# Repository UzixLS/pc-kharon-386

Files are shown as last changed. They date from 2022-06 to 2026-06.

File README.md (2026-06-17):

## Kharon-386
10x10cm IBM PC compatible machine with 386 CPU, integrated VGA and sound.

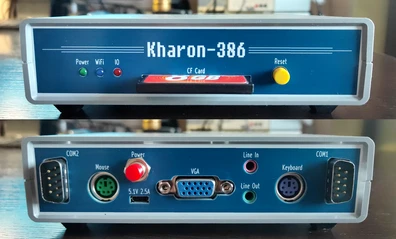
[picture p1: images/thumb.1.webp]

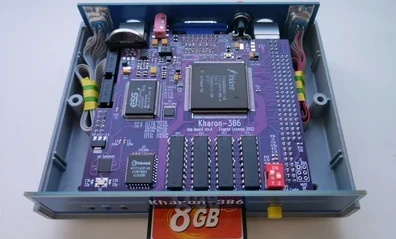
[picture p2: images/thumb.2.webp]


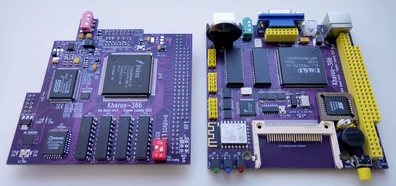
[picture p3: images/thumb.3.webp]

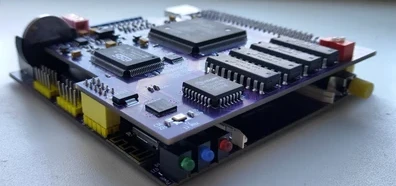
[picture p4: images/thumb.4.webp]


More random photos: [link](https://cloud.err200.net/index.php/s/73TR85tYZkMm8Ax?path=%2Fkharon-386)

### Tech specs
* M6117D System-On-Chip with integrated 386SX40 (almost compatible) CPU and M1217B chipset
* 4MB RAM
* TVGA9000i VGA video
* ES1868F SoundBlasterPro-compatible sound
* SAM2695 MIDI synthesizer
* ESP8266 WiFi module
* PS/2 keyboard and mouse inputs
* 2xCOM ports
* CF card slot
* Real-time clock (RTC) with backup battery
* Integrated PC-speaker
* 5.1V microUSB power
* Two 4-layer 10x10cm PCBs + front/back panel PCB
* G738 or G706 enclosure

### Navigation
[release/pcb_main.rev.A1.pdf](release/pcb_main.rev.A1.pdf) - motherboard schematic and bill of materials  
[release/pcb_top.rev.A1.pdf](release/pcb_top.rev.A1.pdf) - video&sound board schematic and bill of materials  
[release/bom_interactive_main.rev.A1.html](https://htmlpreview.github.io/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) - motherboard interactive BOM  
[release/bom_interactive_top.rev.A1.html](https://htmlpreview.github.io/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) - video&sound board interactive BOM  
[release/gerber_main.rev.A1.zip](release/gerber_main.rev.A1.zip) - motherboard fabrication files  
[release/gerber_top.rev.A1.zip](release/gerber_top.rev.A1.zip) - video&sound board fabrication files  
[release/gerber_covers.rev.A.zip](release/gerber_covers.rev.A.zip) - front and back panel fabrication files  
[roms/M6117 - award+ami.bin](roms/M6117%20-%20award+ami.bin) - main BIOS image  
[roms/tvga9000i - D3.51 + D4.01E.bin](roms/tvga9000i%20-%20D3.51%20%2B%20D4.01E.bin) - VGA BIOS image  
[software/msdos622_compactflash_2GB.7z](software/msdos622_compactflash_2GB.7z) - CF card image with preinstalled MS-DOS 6.22 and all necessary drivers

### WiFi module
There is two options how to use WiFi module:
1. Zimodem ([link](https://github.com/bozimmerman/Zimodem)) - provides ability to connect to BBS via any terminal without using additional software. WiFi module is connected to COM4, so you can use any terminal to communicate with it using AT commands.
2. esp_slip_router ([link](https://github.com/martin-ger/esp_slip_router)) - provides ability to connect your machine to IP network just like as Ethernet. You need ETHERSLIP or similar packet driver for DOS.

To upload firmware you need USB-UART adapter with 3.3V signal levels. Connect GND, RX and TX lines to esp header located on main PCB at left, install BOOT/GND jumper and follow any ESP8266 firmware update guide that is available on the internet.

### Sound mixer
MIDI synthesizer is connected to the AUXB sound input of ES1868F. Usually this input named as "CD input" in mixer software.  
PC speaker is connected to the AUXA input.  
To obtain a minimum noise level, it is recommended to disable line input in the mixer.

### Changelog & current status
Main PCB:
* Rev.A - first release. Please note the [errata](pcb_main/rev.A/ERRATA.txt);
* Rev.A1 - fixed all rev.A issues; added switch for BIOS variant select; added optional -5V source. Please note the [errata](pcb_main/rev.A1/ERRATA.txt).

Top PCB:
* Rev.A - first release. Please note the [errata](pcb_top/rev.A/ERRATA.txt);
* Rev.A1 - fixed all rev.A issues; added switch for VGA BIOS variant select; removed VGA-disable switch; added EEPROM for ES1868.

Covers PCB:
* Rev.A - first release.

### Related projects
I want to express my appreciation to the authors of the following projects, which served as inspiration and as reference for my development:

[http://www.alexandrugroza.ro/microelectronics/system-design/isa-80386dx-sbmc/index.html](http://www.alexandrugroza.ro/microelectronics/system-design/isa-80386dx-sbmc/index.html) - 80386DX ISA single board microcomputer by Alexandru Groza  
[https://bitbucket.org/Haper/poisk-2-mainboard/src/master/](https://bitbucket.org/Haper/poisk-2-mainboard/src/master/) - XT compatible 8086-based machine, reverse engineered by Andrew Khapoknysh ([details](https://habr.com/ru/articles/407265/))  
[http://www.malinov.com/Home/sergeys-projects/xi-8088](http://www.malinov.com/Home/sergeys-projects/xi-8088) - IBM PC/XT compatible processor board in ISA board form factor by by Sergey Kiselev  
[https://github.com/skiselev/micro_8088](https://github.com/skiselev/micro_8088) - IBM XT compatible processor board based on Faraday FE2010 chipset by Sergey Kiselev  
[https://github.com/monotech/NuXT](https://github.com/monotech/NuXT) -  MicroATX Turbo XT Motherboard, with VGA, floppy, CF, serial by Monotech  
[http://www.malinov.com/Home/sergeys-projects/isa-supervga](http://www.malinov.com/Home/sergeys-projects/isa-supervga) - ISA Super VGA card based on the Trident TVGA9000i Super VGA controller IC by Sergey Kiselev  
[https://github.com/monotech/PC104-SVGA](https://github.com/monotech/PC104-SVGA) - 8088-compatible 8-bit ISA PC/104 SVGA card by Monotech
[https://github.com/hkzlab/ES1868_ISA8](https://github.com/hkzlab/ES1868_ISA8) - ISA 8bit sound card based on the ES1868F sound chip by hkzlab

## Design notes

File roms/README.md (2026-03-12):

## ROM files

* **M6117 - award+ami.bin** — for the main PCB (U14) - system BIOS. Two alternative variants are included and can be selected using SW3. The AMI BIOS is recommended.
* **tvga9000i - D3.51 + D4.01E.bin** — for the top PCB (U7); video BIOS. Two alternative variants are included and can be selected using SW1.1.
* **AT93C66-dump.bin** — for the top PCB (U10); sound card PnP options. This ROM is optional, use it only if you experience problems with IRQ/DMA resource assignment.

All ROMs must be flashed before being soldered onto the PCB; in-circuit programming is not possible.

You can use any suitable ROM programmer (for example, TL866II). For detailed instructions, refer to the manufacturer’s manual.

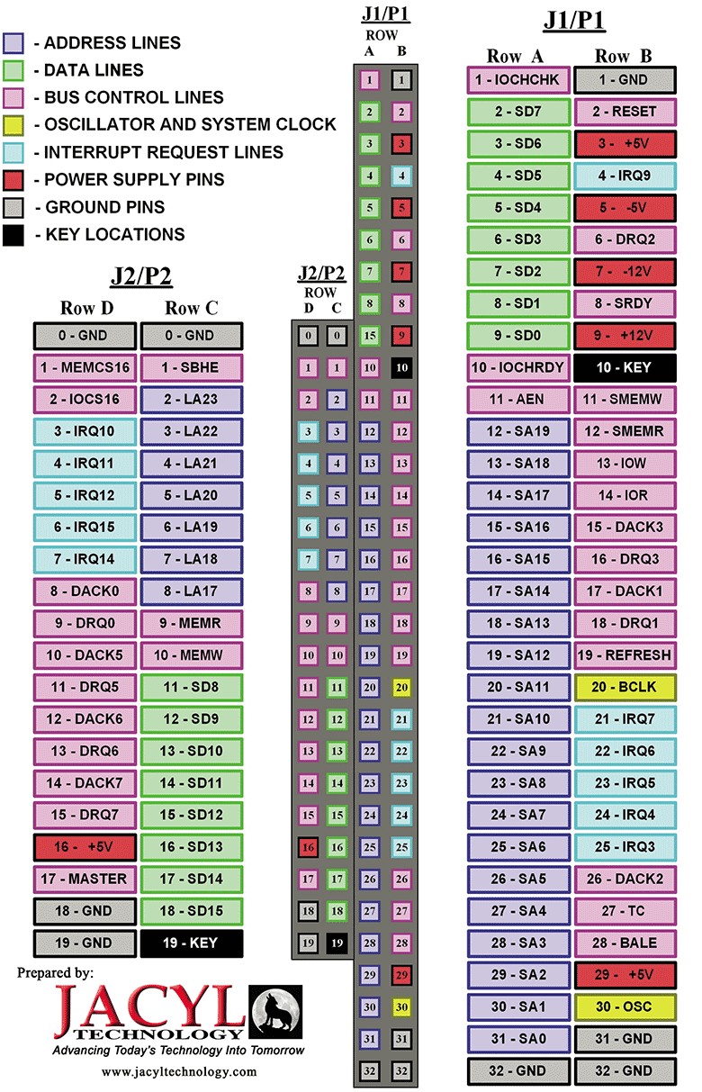
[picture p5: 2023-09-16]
datasheets/pc104.jpeg

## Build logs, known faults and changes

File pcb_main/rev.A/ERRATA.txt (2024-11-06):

1. Incorrect reset circuit
2. Unstable -12V under load. 1k resistor should be added between +12V and GND
3. BIOS PLCC socked interferes with CF card slot
4. U15 should be TXS0104PW
5. Incorrent IRQ routing for COM3 and COM4
6. U17 should not be installed
7. Incorrect CTS/RTS connection on ESP8266
8. C3 should not be installed

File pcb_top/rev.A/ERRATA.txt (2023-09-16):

1. ES1868F sounds too quiet
   - R10, R12 should be 0 Ohm
   - R14, R15 should not be installed
   - C20, C25 should be 1 uF
   - R11, R13 should be 10 KOhm
2. ES1868F footprint is a bit smaller than required, so soldering it may be tricky

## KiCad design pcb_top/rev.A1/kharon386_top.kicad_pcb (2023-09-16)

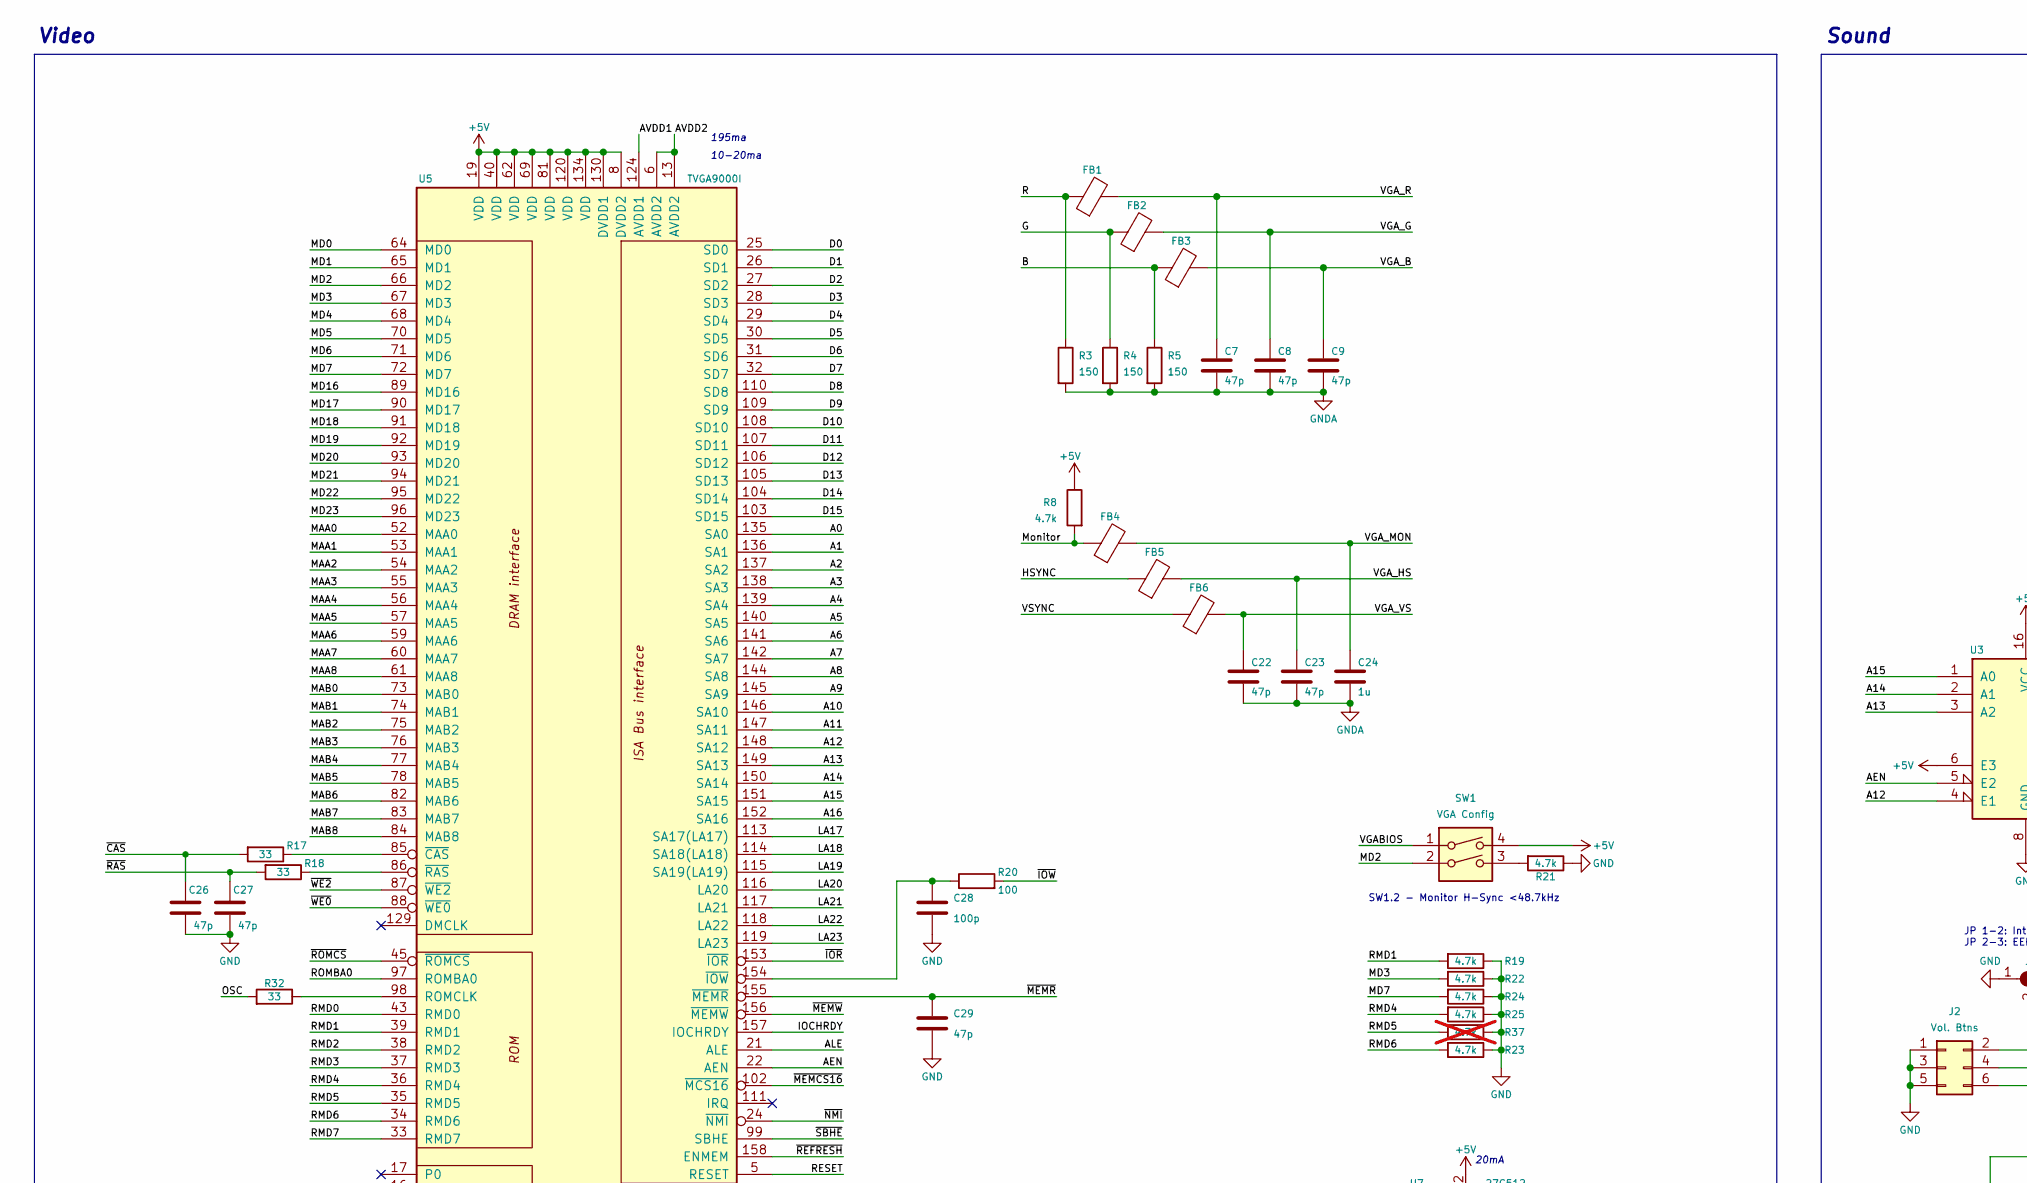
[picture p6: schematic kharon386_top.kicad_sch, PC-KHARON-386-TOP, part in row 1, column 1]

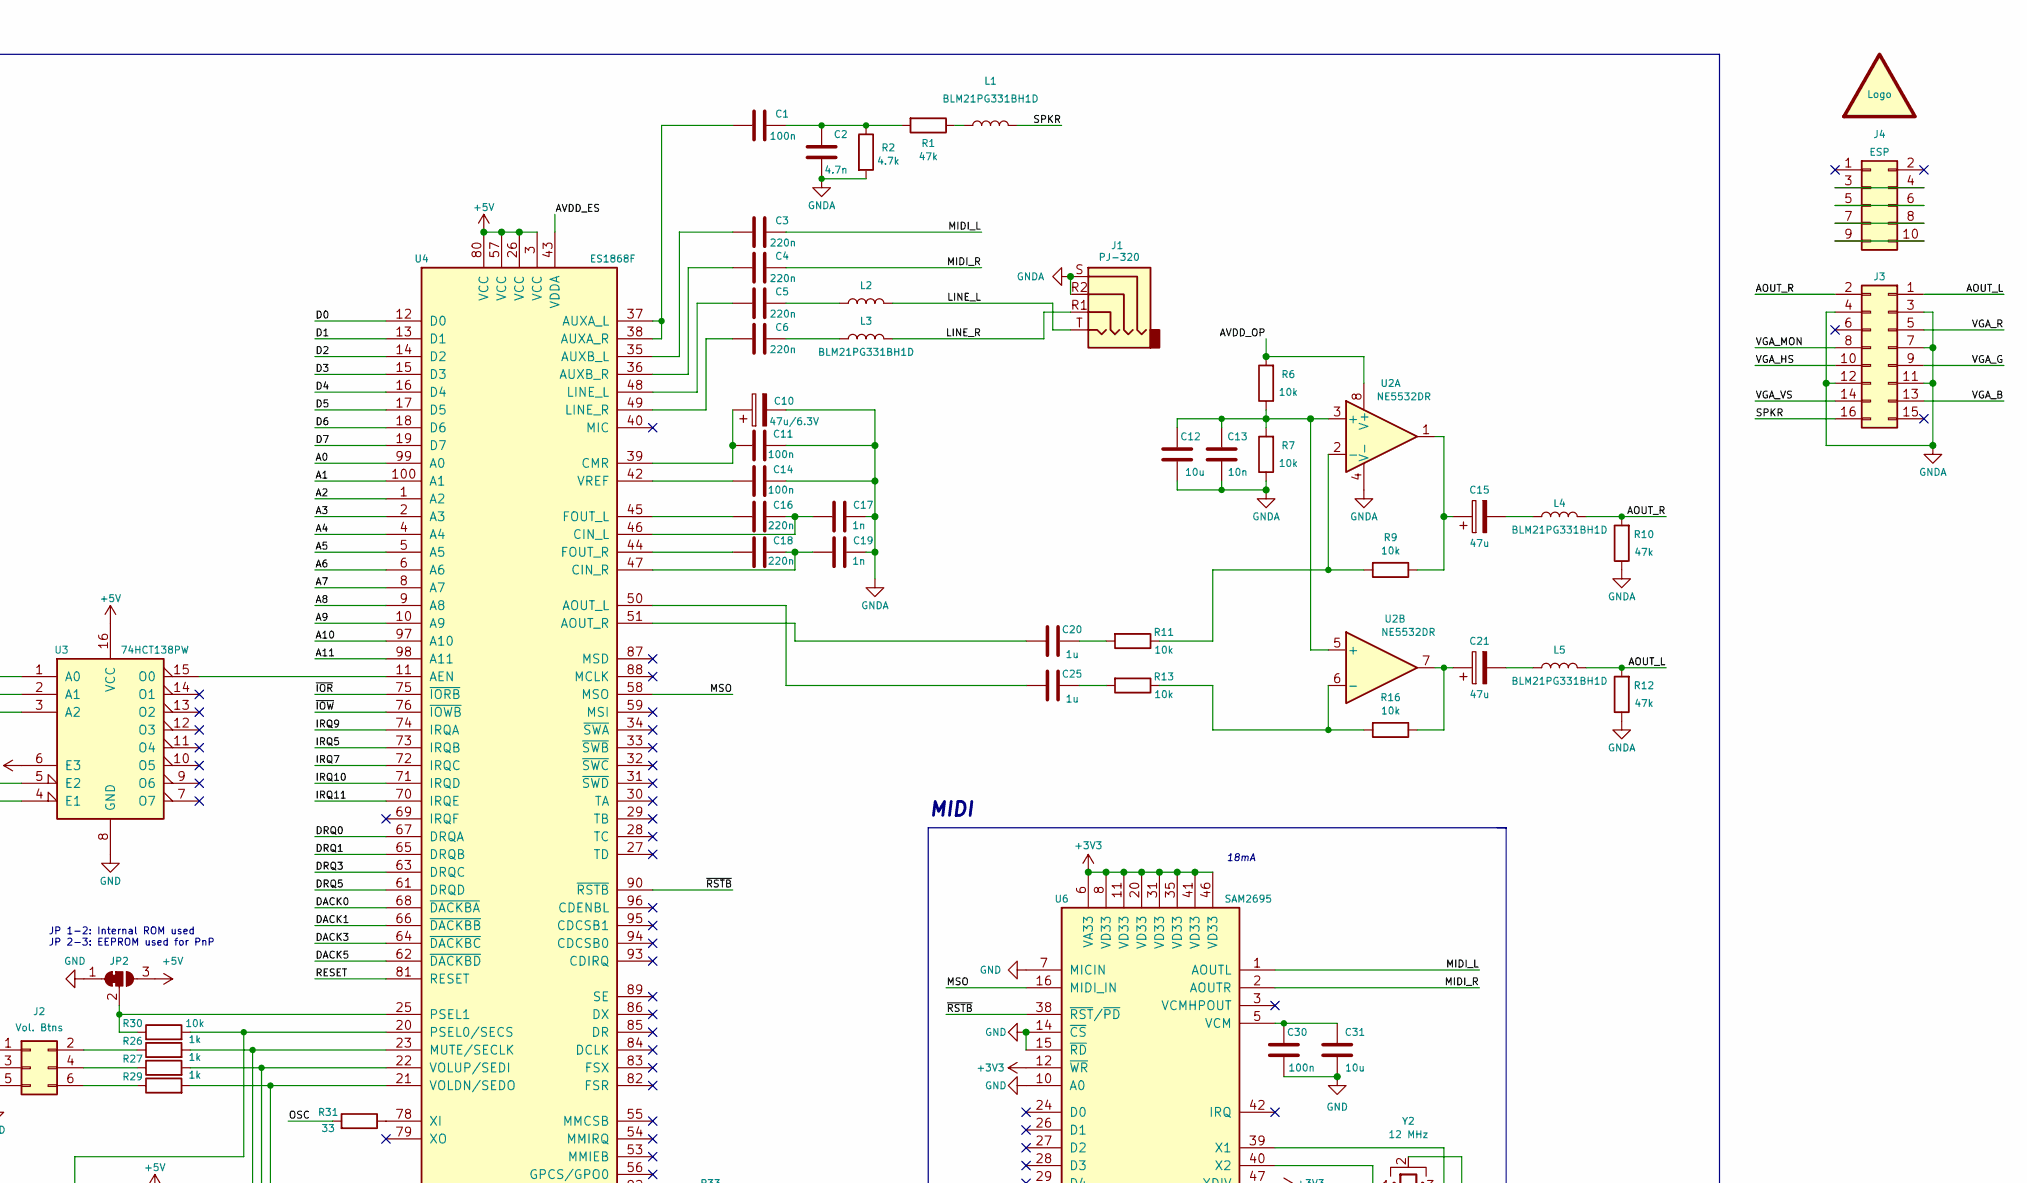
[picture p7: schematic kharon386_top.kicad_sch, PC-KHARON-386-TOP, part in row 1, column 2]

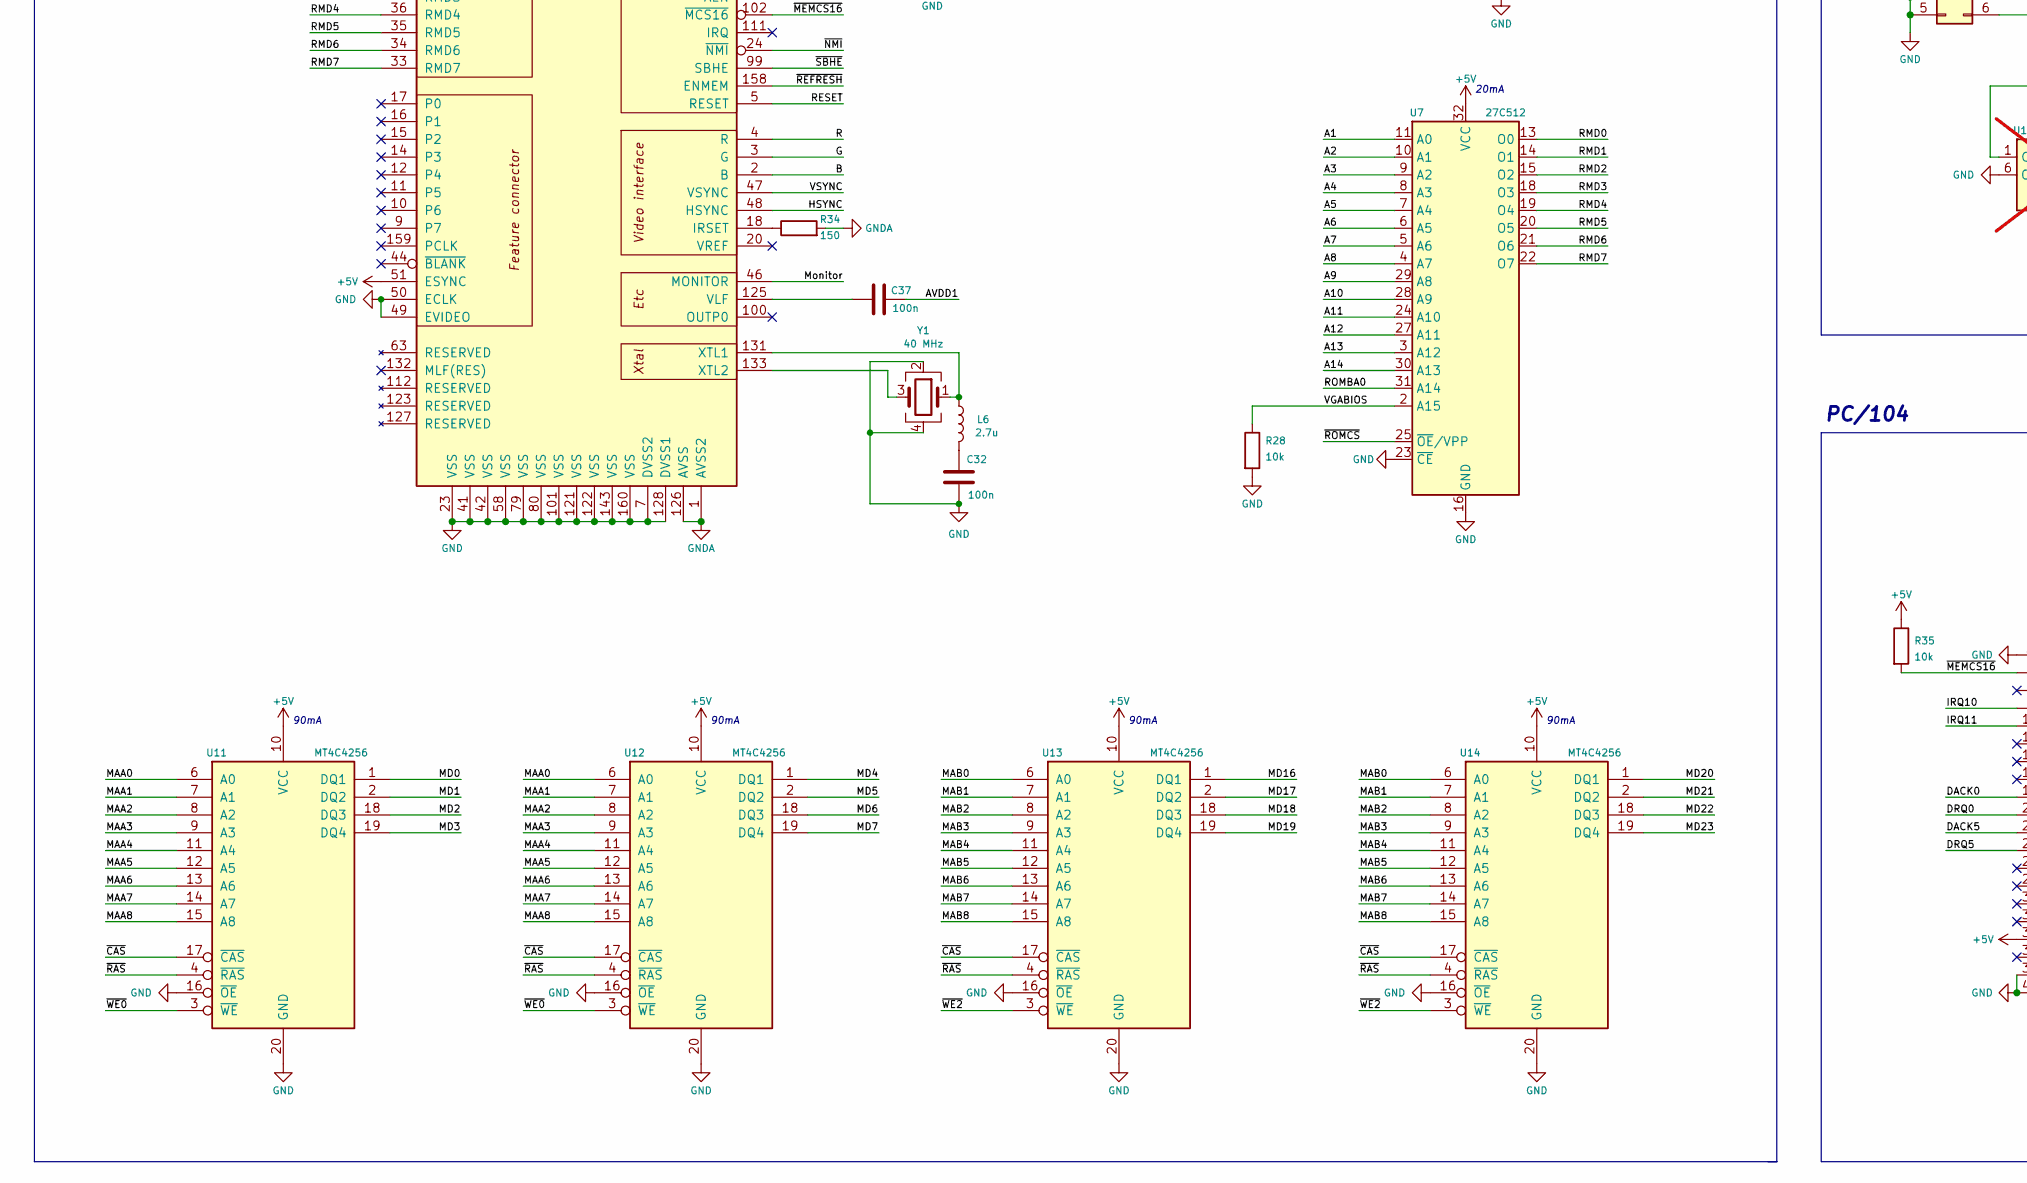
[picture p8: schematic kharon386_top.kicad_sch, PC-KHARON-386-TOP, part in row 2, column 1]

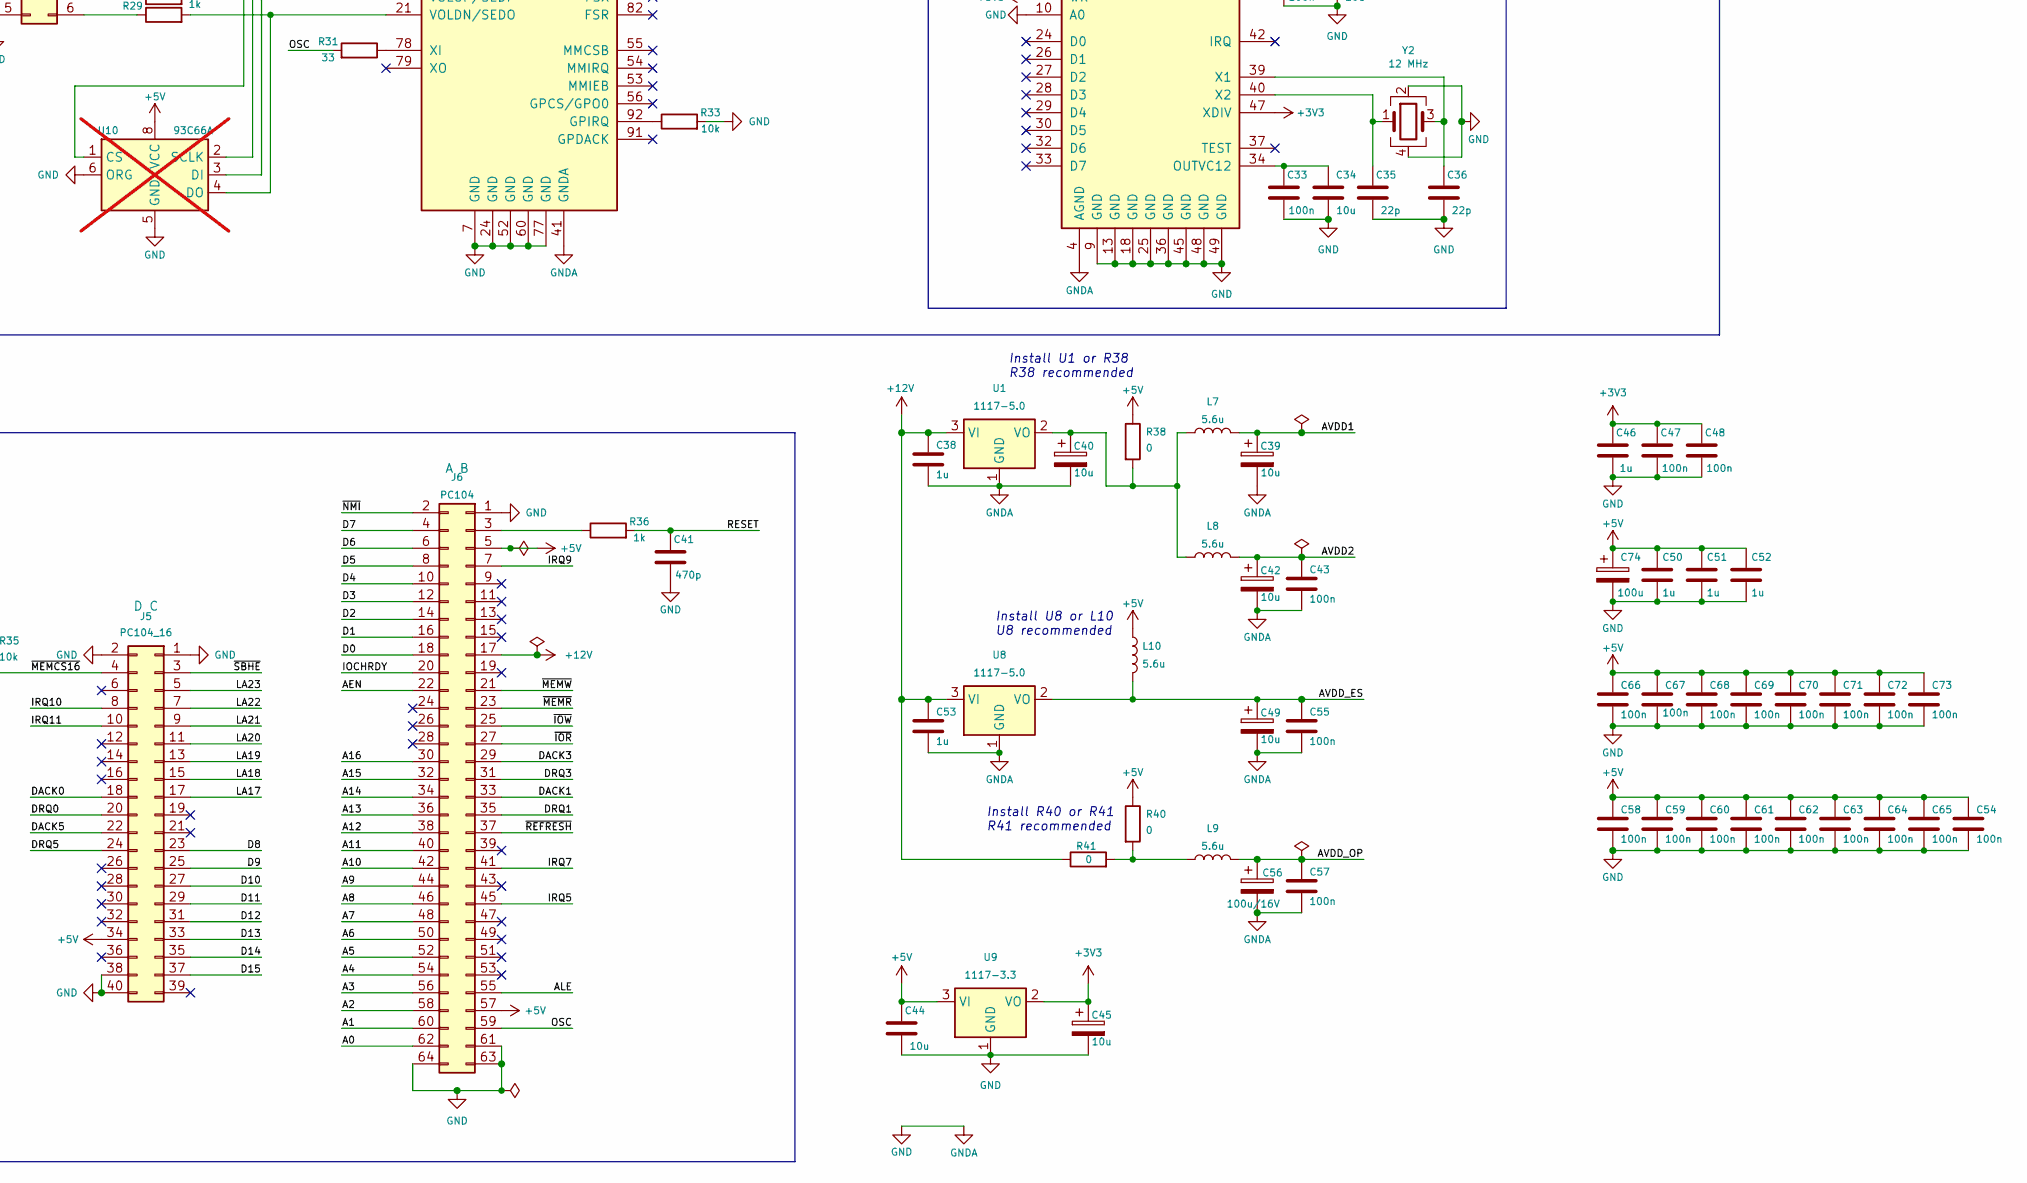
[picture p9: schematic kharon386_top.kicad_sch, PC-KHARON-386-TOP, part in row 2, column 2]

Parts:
C1, C11, C14, C30, C32, C33, C37, C43, C47, C48, C54, C55, C57, C58, C59, C60, C61, C62, C63, C64, C65, C66, C67, C68, C69, C70, C71, C72, C73: 100n; C_0603_1608Metric_Pad1.08x0.95mm_HandSolder
C2: 4.7n; C_0603_1608Metric_Pad1.08x0.95mm_HandSolder
C3, C4, C5, C6, C16, C18: 220n; C_0603_1608Metric_Pad1.08x0.95mm_HandSolder
C7, C8, C9, C22, C23, C26, C27, C29: 47p; C_0603_1608Metric_Pad1.08x0.95mm_HandSolder
C10: 47u/6.3V; CP_EIA-3528-21_Kemet-B_Pad1.50x2.35mm_HandSolder
C12, C31, C34, C44: 10u; C_0805_2012Metric_Pad1.18x1.45mm_HandSolder
C13: 10n; C_0603_1608Metric_Pad1.08x0.95mm_HandSolder
C15, C21: 47u; CP_EIA-3528-21_Kemet-B_Pad1.50x2.35mm_HandSolder
C17, C19: 1n; C_0603_1608Metric_Pad1.08x0.95mm_HandSolder
C20, C24, C25, C38, C46, C50, C51, C52, C53: 1u; C_0603_1608Metric_Pad1.08x0.95mm_HandSolder
C28: 100p; C_0603_1608Metric_Pad1.08x0.95mm_HandSolder
C35, C36: 22p; C_0603_1608Metric_Pad1.08x0.95mm_HandSolder
C39, C40, C42, C45, C49: 10u; CP_EIA-3216-18_Kemet-A_Pad1.58x1.35mm_HandSolder
C41: 470p; C_0603_1608Metric_Pad1.08x0.95mm_HandSolder
C56: 100u/16V; CP_EIA-6032-28_Kemet-C_Pad2.25x2.35mm_HandSolder
C74: 100u; CP_EIA-7343-31_Kemet-D_Pad2.25x2.55mm_HandSolder
FB1, FB2, FB3, FB4, FB5, FB6: Ferrite_Bead; L_0805_2012Metric_Pad1.15x1.40mm_HandSolder
J1: PJ-320; PJ-320A_D
J2: Vol. Btns; PinHeader_2x03_P2.54mm_Vertical
J3: Conn_02x07_Odd_Even; PinHeader_2x08_P2.54mm_Vertical
J4: ESP; PinSocket_2x05_P2.54mm_Vertical
J5: PC104_16; PinHeader_2x20_P2.54mm_Vertical
J6: PC104; PinHeader_2x32_P2.54mm_Vertical
JP2: SolderJumper_3_Bridged12; SolderJumper-3_P1.3mm_Bridged12_RoundedPad1.0x1.5mm_NumberL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
L1, L2, L3, L4, L5: BLM21PG331BH1D; L_0805_2012Metric_Pad1.15x1.40mm_HandSolder
L6: 2.7u; L_0805_2012Metric_Pad1.15x1.40mm_HandSolder
L7, L8, L9, L10: 5.6u; L_1210_3225Metric_Pad1.42x2.65mm_HandSolder
LOGO1: graphic; black-mage-12.5x8.6
R1, R10, R12: 47k; R_0603_1608Metric_Pad0.98x0.95mm_HandSolder
R2, R8, R19, R21, R22, R23, R24, R25: 4.7k; R_0603_1608Metric_Pad0.98x0.95mm_HandSolder
R3, R4, R5, R34: 150; R_0603_1608Metric_Pad0.98x0.95mm_HandSolder
R6, R7, R9, R11, R13, R16, R28, R30, R33, R35: 10k; R_0603_1608Metric_Pad0.98x0.95mm_HandSolder
R17, R18, R31, R32: 33; R_0603_1608Metric_Pad0.98x0.95mm_HandSolder
R20: 100; R_0603_1608Metric_Pad0.98x0.95mm_HandSolder
R26, R27, R29, R36: 1k; R_0603_1608Metric_Pad0.98x0.95mm_HandSolder
R37: 4.7k; R_0603_1608Metric_Pad0.98x0.95mm_HandSolder; not fitted
R38, R40, R41: 0; R_0805_2012Metric_Pad1.20x1.40mm_HandSolder
SW1: VGA Config; SW_DIP_SPSTx02_Slide_6.7x6.64mm_W7.62mm_P2.54mm_LowProfile
U1, U8: 1117-5.0; SOT-223-3_TabPin2
U2: NE5532DR; SOIC-8_3.9x4.9mm_P1.27mm
U3: 74HCT138PW; TSSOP-16_4.4x5mm_P0.65mm
U4: ES1868F; PQFP-100_14x20mm_P0.65mm_ESxxx
U5: TVGA9000I; PQFP-160_28x28mm_P0.65mm_LongPads
U6: SAM2695; QFN-48-1EP_6x6mm_P0.4mm_EP4.2x4.2mm
U7: 27C512; PLCC-32_11.4x14.0mm_P1.27mm-longpads
U9: 1117-3.3; SOT-223-3_TabPin2
U10: 93C66A; SOIC-8_3.9x4.9mm_P1.27mm; not fitted
U11, U12, U13, U14: MT4C4256; DIP-20_W7.62mm
Y1: 40 MHz; Crystal_SMD_SeikoEpson_TSX3225-4Pin_3.2x2.5mm_HandSoldering
Y2: 12 MHz; Crystal_SMD_SeikoEpson_TSX3225-4Pin_3.2x2.5mm_HandSoldering

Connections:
+3V3: C45.1, C46.2, C47.2, C48.2, U6.6 (VA33), U6.8 (VD33), U6.11 (VD33), U6.12 (~WR), U6.20 (VD33), U6.31 (VD33), U6.35 (VD33), U6.41 (VD33), U6.46 (VD33), U6.47 (XDIV), U9.2 (VO)
+5V: C44.2, C50.1, C51.1, C52.1, C54.1, C58.1, C59.1, C60.1, C61.1, C62.1, C63.1, C64.1, C65.1, C66.1, C67.1, C68.1, C69.1, C70.1, C71.1, C72.1, C73.1, C74.1, J5.34, J6.5, J6.57, JP2.3 (B), L10.1, R8.1, R35.1, R38.1, R40.1, SW1.4, U3.6 (E3), U3.16 (VCC), U4.3 (VCC), U4.26 (VCC), U4.57 (VCC), U4.80 (VCC), U5.8 (DVDD2), U5.19 (VDD), U5.40 (VDD), U5.51 (ESYNC), U5.62 (VDD), U5.69 (VDD), U5.81 (VDD), U5.120 (VDD), U5.130 (DVDD1), U5.134 (VDD), U7.32 (VCC), U9.3 (VI), U10.8 (VCC), U11.10 (VCC), U12.10 (VCC), U13.10 (VCC), U14.10 (VCC)
+12V: C38.1, C53.1, J6.17, R41.1, U1.3 (VI), U8.3 (VI)
/A0: J6.62, U4.99 (A0), U5.135 (SA0)
/A1: J6.60, U4.100 (A1), U5.136 (SA1), U7.11 (A0)
/A2: J6.58, U4.1 (A2), U5.137 (SA2), U7.10 (A1)
/A3: J6.56, U4.2 (A3), U5.138 (SA3), U7.9 (A2)
/A4: J6.54, U4.4 (A4), U5.139 (SA4), U7.8 (A3)
/A5: J6.52, U4.5 (A5), U5.140 (SA5), U7.7 (A4)
/A6: J6.50, U4.6 (A6), U5.141 (SA6), U7.6 (A5)
/A7: J6.48, U4.8 (A7), U5.142 (SA7), U7.5 (A6)
/A8: J6.46, U4.9 (A8), U5.144 (SA8), U7.4 (A7)
/A9: J6.44, U4.10 (A9), U5.145 (SA9), U7.29 (A8)
/A10: J6.42, U4.97 (A10), U5.146 (SA10), U7.28 (A9)
/A11: J6.40, U4.98 (A11), U5.147 (SA11), U7.24 (A10)
/A12: J6.38, U3.4 (E1), U5.148 (SA12), U7.27 (A11)
/A13: J6.36, U3.3 (A2), U5.149 (SA13), U7.3 (A12)
/A14: J6.34, U3.2 (A1), U5.150 (SA14), U7.30 (A13)
/A15: J6.32, U3.1 (A0), U5.151 (SA15)
/A16: J6.30, U5.152 (SA16)
/AEN: J6.22, U3.5 (E2), U5.22 (AEN)
/ALE: J6.55, U5.21 (ALE)
/AOUT_L: J3.1, L5.2, R12.2
/AOUT_R: J3.2, L4.2, R10.2
/AVDD1: C37.2, C39.1, L7.2, U5.124 (AVDD1)
/AVDD2: C42.1, C43.1, L8.2, U5.6 (AVDD2), U5.13 (AVDD2)
/AVDD_ES: C49.1, C55.1, L10.2, U4.43 (VDDA), U8.2 (VO)
/AVDD_OP: C56.1, C57.1, L9.2, R6.2, U2.8 (V+)
/B: FB3.1, R5.1, U5.2 (B)
/D0: J6.18, U4.12 (D0), U5.25 (SD0)
/D1: J6.16, U4.13 (D1), U5.26 (SD1)
/D2: J6.14, U4.14 (D2), U5.27 (SD2)
/D3: J6.12, U4.15 (D3), U5.28 (SD3)
/D4: J6.10, U4.16 (D4), U5.29 (SD4)
/D5: J6.8, U4.17 (D5), U5.30 (SD5)
/D6: J6.6, U4.18 (D6), U5.31 (SD6)
/D7: J6.4, U4.19 (D7), U5.32 (SD7)
/D8: J5.23, U5.110 (SD8)
/D9: J5.25, U5.109 (SD9)
/D10: J5.27, U5.108 (SD10)
/D11: J5.29, U5.107 (SD11)
/D12: J5.31, U5.106 (SD12)
/D13: J5.33, U5.105 (SD13)
/D14: J5.35, U5.104 (SD14)
/D15: J5.37, U5.103 (SD15)
/DACK0: J5.18, U4.68 (~DACKBA)
/DACK1: J6.33, U4.66 (~DACKBB)
/DACK3: J6.29, U4.64 (~DACKBC)
/DACK5: J5.22, U4.62 (~DACKBD)
/DRQ0: J5.20, U4.67 (DRQA)
/DRQ1: J6.35, U4.65 (DRQB)
/DRQ3: J6.31, U4.63 (DRQC)
/DRQ5: J5.24, U4.61 (DRQD)
/G: FB2.1, R4.1, U5.3 (G)
/HSYNC: FB5.1, U5.48 (HSYNC)
/IOCHRDY: J6.20, U5.157 (IOCHRDY)
/IRQ5: J6.45, U4.73 (IRQB)
/IRQ7: J6.41, U4.72 (IRQC)
/IRQ9: J6.7, U4.74 (IRQA)
/IRQ10: J5.8, U4.71 (IRQD)
/IRQ11: J5.10, U4.70 (IRQE)
/LA17: J5.17, U5.113 (SA17(LA17))
/LA18: J5.15, U5.114 (SA18(LA18))
/LA19: J5.13, U5.115 (SA19(LA19))
/LA20: J5.11, U5.116 (LA20)
/LA21: J5.9, U5.117 (LA21)
/LA22: J5.7, U5.118 (LA22)
/LA23: J5.5, U5.119 (LA23)
/LINE_L: J1.T, L2.2
/LINE_R: J1.R1, L3.2
/MAA0: U5.52 (MAA0), U11.6 (A0), U12.6 (A0)
/MAA1: U5.53 (MAA1), U11.7 (A1), U12.7 (A1)
/MAA2: U5.54 (MAA2), U11.8 (A2), U12.8 (A2)
/MAA3: U5.55 (MAA3), U11.9 (A3), U12.9 (A3)
/MAA4: U5.56 (MAA4), U11.11 (A4), U12.11 (A4)
/MAA5: U5.57 (MAA5), U11.12 (A5), U12.12 (A5)
/MAA6: U5.59 (MAA6), U11.13 (A6), U12.13 (A6)
/MAA7: U5.60 (MAA7), U11.14 (A7), U12.14 (A7)
/MAA8: U5.61 (MAA8), U11.15 (A8), U12.15 (A8)
/MAB0: U5.73 (MAB0), U13.6 (A0), U14.6 (A0)
/MAB1: U5.74 (MAB1), U13.7 (A1), U14.7 (A1)
/MAB2: U5.75 (MAB2), U13.8 (A2), U14.8 (A2)
/MAB3: U5.76 (MAB3), U13.9 (A3), U14.9 (A3)
/MAB4: U5.77 (MAB4), U13.11 (A4), U14.11 (A4)
/MAB5: U5.78 (MAB5), U13.12 (A5), U14.12 (A5)
/MAB6: U5.82 (MAB6), U13.13 (A6), U14.13 (A6)
/MAB7: U5.83 (MAB7), U13.14 (A7), U14.14 (A7)
/MAB8: U5.84 (MAB8), U13.15 (A8), U14.15 (A8)
/MD0: U5.64 (MD0), U11.1 (DQ1)
/MD1: U5.65 (MD1), U11.2 (DQ2)
/MD2: SW1.2, U5.66 (MD2), U11.18 (DQ3)
/MD3: R22.2, U5.67 (MD3), U11.19 (DQ4)
/MD4: U5.68 (MD4), U12.1 (DQ1)
/MD5: U5.70 (MD5), U12.2 (DQ2)
/MD6: U5.71 (MD6), U12.18 (DQ3)
/MD7: R24.2, U5.72 (MD7), U12.19 (DQ4)
/MD16: U5.89 (MD16), U13.1 (DQ1)
/MD17: U5.90 (MD17), U13.2 (DQ2)
/MD18: U5.91 (MD18), U13.18 (DQ3)
/MD19: U5.92 (MD19), U13.19 (DQ4)
/MD20: U5.93 (MD20), U14.1 (DQ1)
/MD21: U5.94 (MD21), U14.2 (DQ2)
/MD22: U5.95 (MD22), U14.18 (DQ3)
/MD23: U5.96 (MD23), U14.19 (DQ4)
/MIDI_L: C3.2, U6.1 (AOUTL)
/MIDI_R: C4.2, U6.2 (AOUTR)
/MSO: U4.58 (MSO), U6.16 (MIDI_IN)
/Monitor: FB4.1, R8.2, U5.46 (MONITOR)
/OSC: J6.59, R31.2, R32.2
/R: FB1.1, R3.1, U5.4 (R)
/RESET: C41.1, R36.2, U4.81 (RESET), U5.5 (RESET)
/RMD0: U5.43 (RMD0), U7.13 (O0)
/RMD1: R19.2, U5.39 (RMD1), U7.14 (O1)
/RMD2: U5.38 (RMD2), U7.15 (O2)
/RMD3: U5.37 (RMD3), U7.18 (O3)
/RMD4: R25.2, U5.36 (RMD4), U7.19 (O4)
/RMD5: R37.2, U5.35 (RMD5), U7.20 (O5)
/RMD6: R23.2, U5.34 (RMD6), U7.21 (O6)
/RMD7: U5.33 (RMD7), U7.22 (O7)
/ROMBA0: U5.97 (ROMBA0), U7.31 (A14)
/SPKR: J3.16, L1.2
/VGABIOS: R28.1, SW1.1, U7.2 (A15)
/VGA_B: C9.1, FB3.2, J3.13
/VGA_G: C8.1, FB2.2, J3.9
/VGA_HS: C23.1, FB5.2, J3.10
/VGA_MON: C24.1, FB4.2, J3.8
/VGA_R: C7.1, FB1.2, J3.5
/VGA_VS: C22.1, FB6.2, J3.14
/VSYNC: FB6.1, U5.47 (VSYNC)
/~CAS: C26.2, R17.2, U11.17 (~CAS), U12.17 (~CAS), U13.17 (~CAS), U14.17 (~CAS)
/~IOR: J6.27, U4.75 (~IORB), U5.153 (~IOR)
/~IOW: J6.25, R20.2, U4.76 (~IOWB)
/~MEMCS16: J5.4, R35.2, U5.102 (~MCS16)
/~MEMR: C29.1, J6.23, U5.155 (~MEMR)
/~MEMW: J6.21, U5.156 (~MEMW)
/~NMI: J6.2, U5.24 (~NMI)
/~RAS: C27.2, R18.2, U11.4 (~RAS), U12.4 (~RAS), U13.4 (~RAS), U14.4 (~RAS)
/~REFRESH: J6.37, U5.158 (ENMEM)
/~ROMCS: U5.45 (~ROMCS), U7.25 (~OE/VPP)
/~RSTB: U4.90 (~RSTB), U6.38 (~RST/~PD)
/~SBHE: J5.3, U5.99 (SBHE)
/~WE0: U5.88 (~WE0), U11.3 (~WE), U12.3 (~WE)
/~WE2: U5.87 (~WE2), U13.3 (~WE), U14.3 (~WE)
GND: C2.1, C7.2, C8.2, C9.2, C10.2, C11.2, C12.1, C13.1, C14.2, C17.2, C19.2, C22.2, C23.2, C24.2, C26.1, C27.1, C28.2, C29.2, C30.1, C31.1, C32.1, C33.1, C34.1, C35.1, C36.1, C38.2, C39.2, C40.2, C41.2, C42.2, C43.2, C44.1, C45.2, C46.1, C47.1, C48.1, C49.2, C50.2, C51.2, C52.2, C53.2, C54.2, C55.2, C56.2, C57.2, C58.2, C59.2, C60.2, C61.2, C62.2, C63.2, C64.2, C65.2, C66.2, C67.2, C68.2, C69.2, C70.2, C71.2, C72.2, C73.2, C74.2, J1.R2, J1.S, J2.1, J2.3, J2.5, J3.3, J3.4, J3.7, J3.11, J3.12, J5.1, J5.2, J5.38, J5.40, J6.1, J6.61, J6.63, J6.64, JP2.1 (A), R2.2, R3.2, R4.2, R5.2, R7.1, R10.1, R12.1, R19.1, R21.1, R22.1, R23.1, R24.1, R25.1, R28.2, R33.2, R34.2, R37.1, U1.1 (GND), U2.4 (V-), U3.8 (GND), U4.7 (GND), U4.24 (GND), U4.41 (GNDA), U4.52 (GND), U4.60 (GND), U4.77 (GND), U5.1 (AVSS2), U5.7 (DVSS2), U5.23 (VSS), U5.41 (VSS), U5.42 (VSS), U5.49 (EVIDEO), U5.50 (ECLK), U5.58 (VSS), U5.79 (VSS), U5.80 (VSS), U5.101 (VSS), U5.121 (VSS), U5.122 (VSS), U5.126 (AVSS), U5.128 (DVSS1), U5.143 (VSS), U5.160 (VSS), U6.4 (AGND), U6.7 (MICIN), U6.9 (GND), U6.10 (A0), U6.13 (GND), U6.14 (~CS), U6.15 (~RD), U6.18 (GND), U6.25 (GND), U6.36 (GND), U6.45 (GND), U6.48 (GND), U6.49 (GND), U7.16 (GND), U7.23 (~CE), U8.1 (GND), U9.1 (GND), U10.5 (GND), U10.6 (ORG), U11.16 (~OE), U11.20 (GND), U12.16 (~OE), U12.20 (GND), U13.16 (~OE), U13.20 (GND), U14.16 (~OE), U14.20 (GND), Y1.2, Y1.4, Y2.2, Y2.4
unnamed: C1.2, C2.2, R1.2, R2.1
unnamed: C5.2, L2.1
unnamed: C6.2, L3.1
unnamed: C15.1, R9.1, U2.1
unnamed: C15.2, L4.1
unnamed: C20.2, R11.2
unnamed: C21.1, R16.1, U2.7
unnamed: C21.2, L5.1
unnamed: C25.2, R13.2
unnamed: C32.2, L6.1
unnamed: J2.2, R26.1
unnamed: J2.4, R27.1
unnamed: J2.6, R29.1
unnamed: J4.3, J4.4
unnamed: J4.5, J4.6
unnamed: J4.7, J4.8
unnamed: J4.9, J4.10
unnamed: J6.3, R36.1
unnamed: JP2.2 (C), R30.1, U4.25 (PSEL1)
unnamed: L1.1, R1.1
unnamed: L9.1, R40.2, R41.2
unnamed: R21.2, SW1.3
unnamed: C40.1, L7.1, L8.1, R38.2, U1.2 (VO)
unnamed: C12.2, C13.2, R6.1, R7.2, U2.3 (+), U2.5 (+)
unnamed: R9.2, R11.1, U2.2 (-)
unnamed: R13.1, R16.2, U2.6 (-)
unnamed: U3.15 (O0), U4.11 (AEN)
unnamed: C25.1, U4.50 (AOUT_L)
unnamed: C20.1, U4.51 (AOUT_R)
unnamed: C1.1, U4.37 (AUXA_L), U4.38 (AUXA_R)
unnamed: C3.1, U4.35 (AUXB_L)
unnamed: C4.1, U4.36 (AUXB_R)
unnamed: C16.2, C17.1, U4.46 (CIN_L)
unnamed: C18.2, C19.1, U4.47 (CIN_R)
unnamed: C10.1, C11.1, U4.39 (CMR)
unnamed: C16.1, U4.45 (FOUT_L)
unnamed: C18.1, U4.44 (FOUT_R)
unnamed: R33.1, U4.92 (GPIRQ)
unnamed: C5.1, U4.48 (LINE_L)
unnamed: C6.1, U4.49 (LINE_R)
unnamed: C14.1, U4.42 (VREF)
unnamed: R31.1, U4.78 (XI)
unnamed: R34.1, U5.18 (IRSET)
unnamed: R32.1, U5.98 (ROMCLK)
unnamed: C37.1, U5.125 (VLF)
unnamed: L6.2, U5.131 (XTL1), Y1.1
unnamed: U5.133 (XTL2), Y1.3
unnamed: R17.1, U5.85 (~CAS)
unnamed: C28.1, R20.1, U5.154 (~IOW)
unnamed: R18.1, U5.86 (~RAS)
unnamed: C33.2, C34.2, U6.34 (OUTVC12)
unnamed: C30.2, C31.2, U6.5 (VCM)
unnamed: C36.2, U6.39 (X1), Y2.3
unnamed: C35.2, U6.40 (X2), Y2.1
unnamed: R30.2, U4.20 (PSEL0/SECS), U10.1 (CS)
unnamed: R27.2, U4.22 (VOLUP/SEDI), U10.3 (DI)
unnamed: R29.2, U4.21 (VOLDN/SEDO), U10.4 (DO)
unnamed: R26.2, U4.23 (MUTE/SECLK), U10.2 (SCLK)

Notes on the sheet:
10-20ma
JP 1-2: Internal ROM used JP 2-3: EEPROM used for PnP
SW1.2 - Monitor H-Sync <48.7kHz
90mA
18mA
195ma
Install U1 or R38 R38 recommended
Sound
Video
Install U8 or L10 U8 recommended
MIDI
20mA
Install R40 or R41 R41 recommended
PC/104

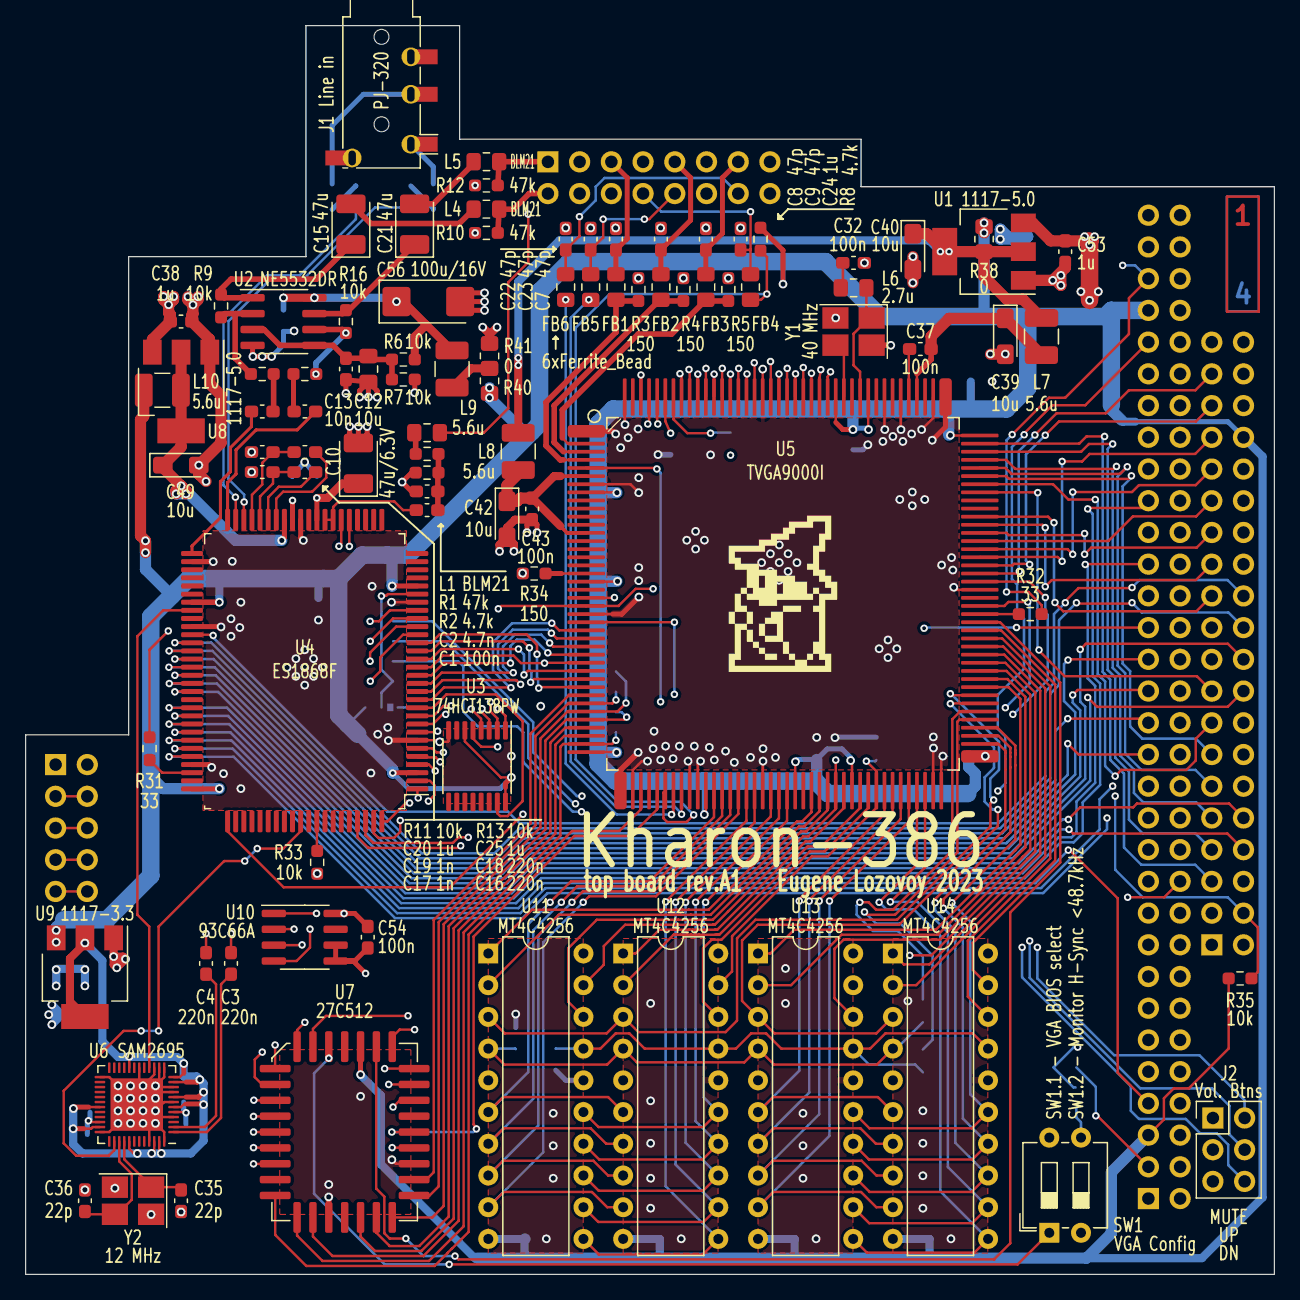
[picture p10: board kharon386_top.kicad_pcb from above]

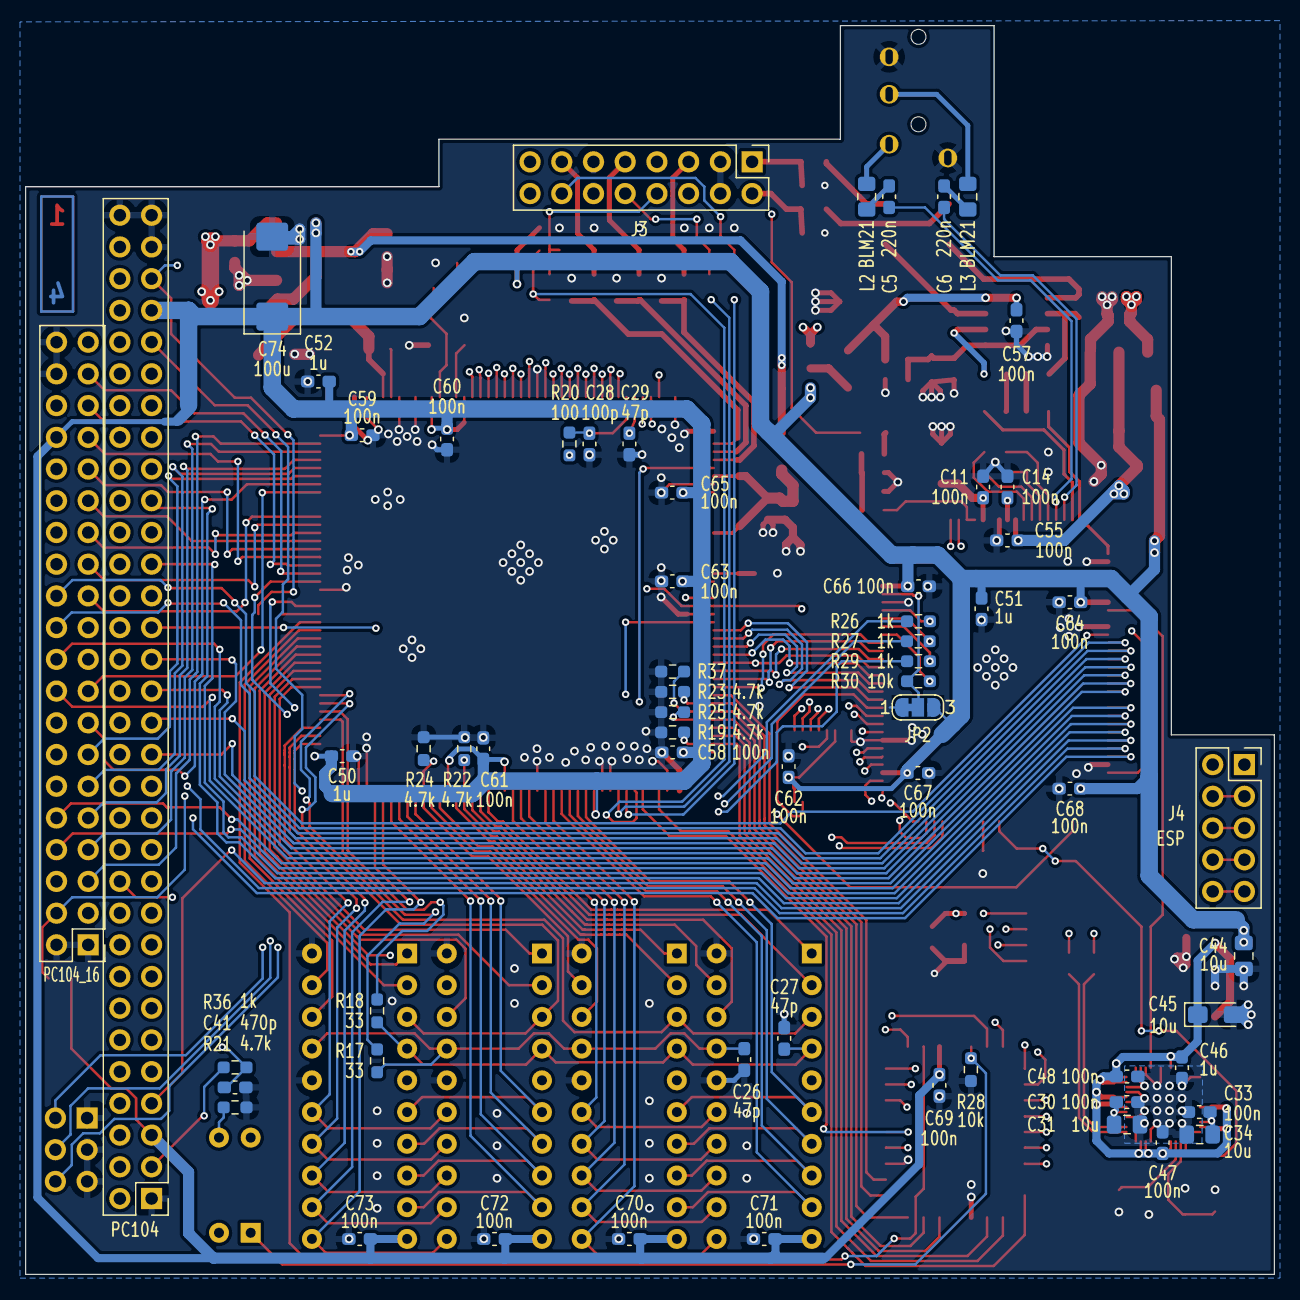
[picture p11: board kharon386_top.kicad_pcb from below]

Board: 4 copper layers, 100.0 x 100.0 mm, 153 parts (63 on the bottom side), 202 nets.

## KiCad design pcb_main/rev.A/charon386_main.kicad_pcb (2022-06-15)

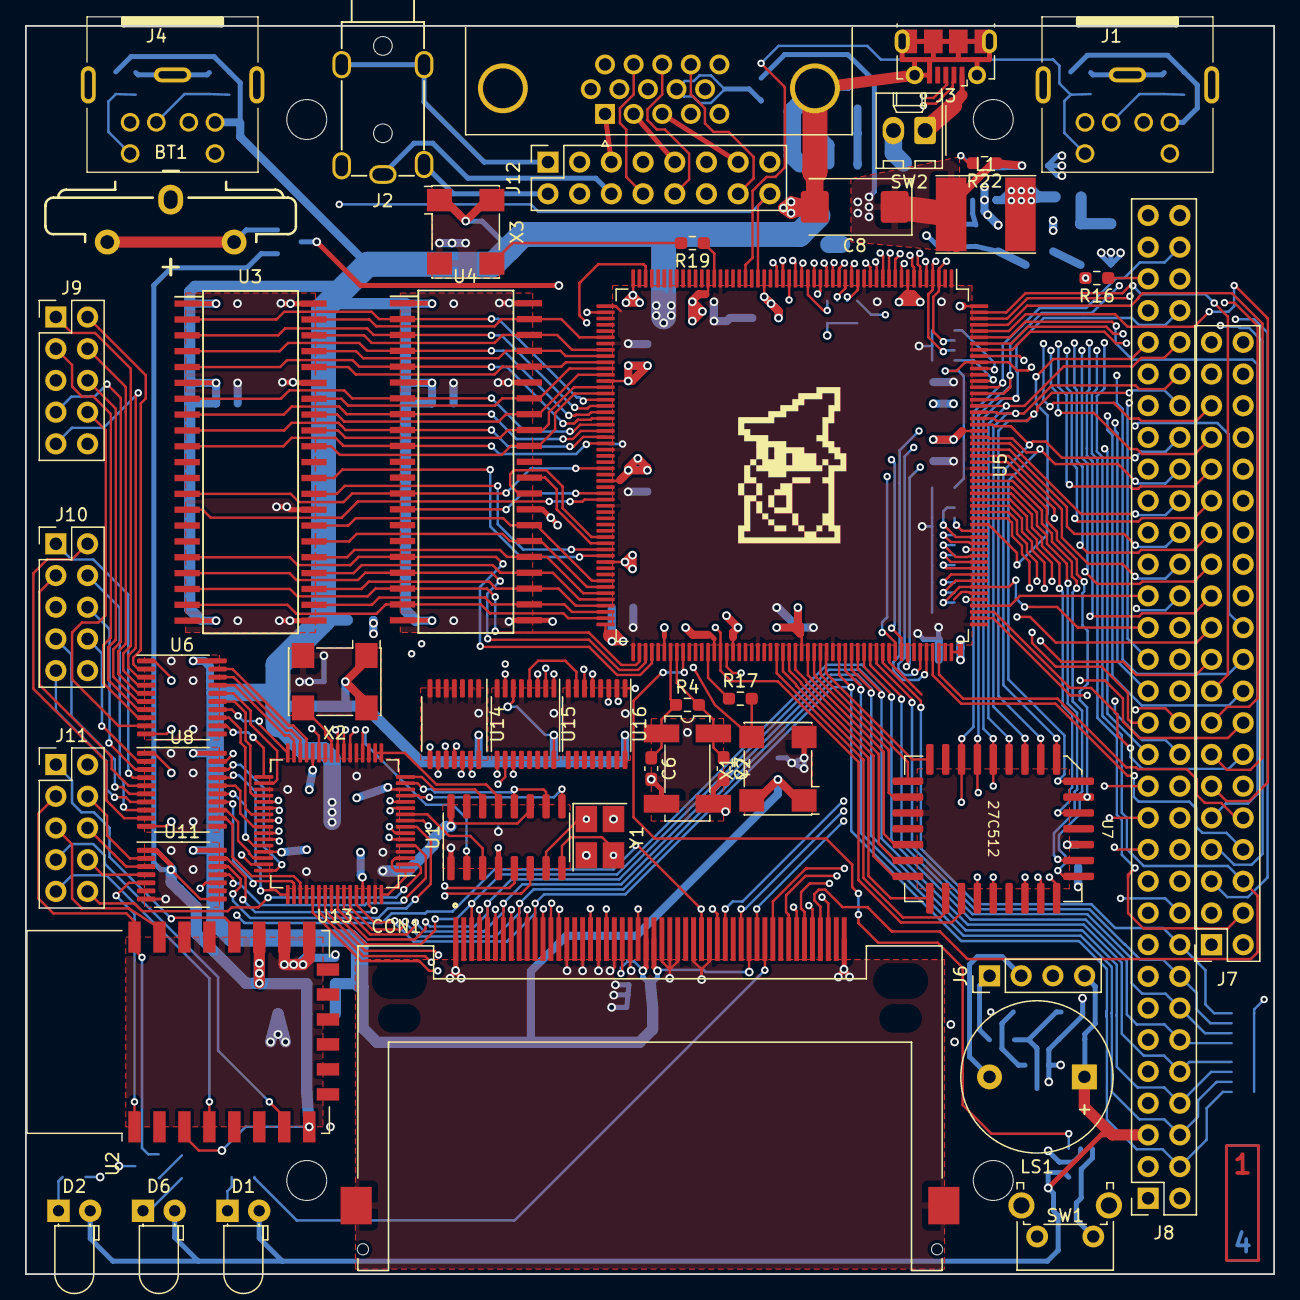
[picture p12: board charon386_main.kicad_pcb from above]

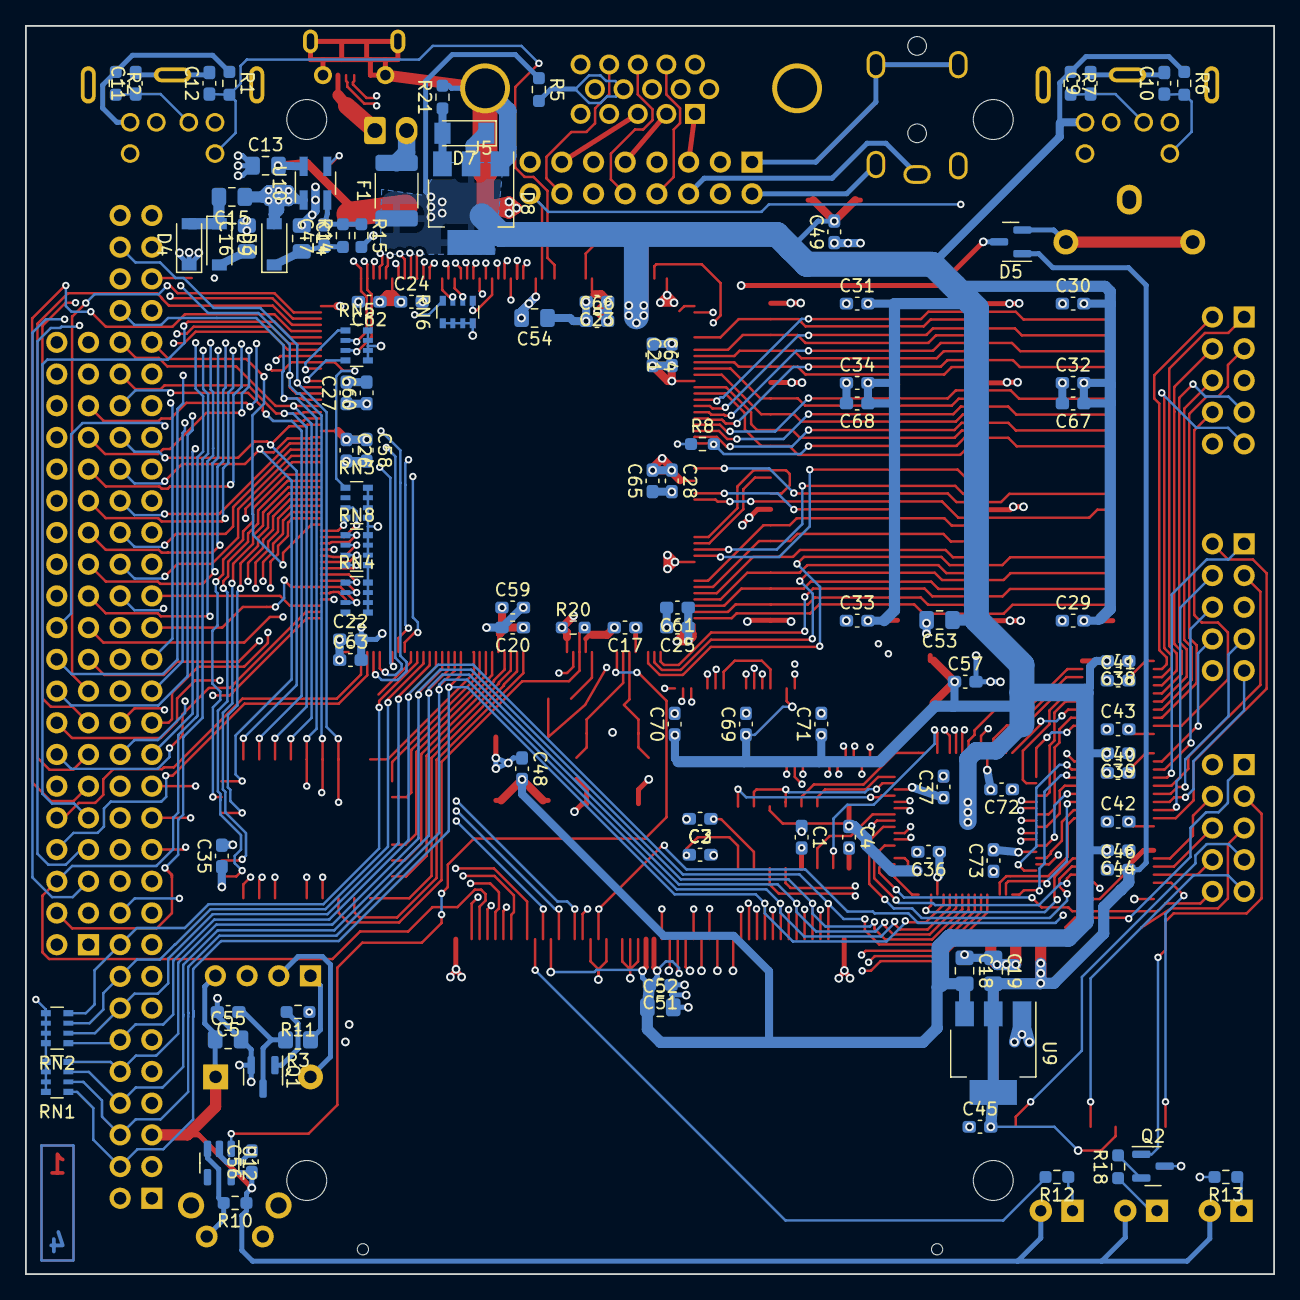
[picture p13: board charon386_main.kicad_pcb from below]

Board: 4 copper layers, 100.0 x 100.0 mm, 156 parts (104 on the bottom side), 245 nets.

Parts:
BT1: 1775485-1 or S8401-46; CR2032V
C1, C5: 10n; C_0603_1608Metric_Pad1.08x0.95mm_HandSolder
C2, C3: 22p; C_0603_1608Metric_Pad1.08x0.95mm_HandSolder
C4, C17, C20, C21, C22, C23, C24, C25, C26, C27, C28, C29, C30, C31, C32, C33, C34, C35, C36, C37, C38, C39, C40, C41, C42, C43, C44, C45, C46, C48, C49, C51, C56, C57, C69, C70, C71, C72, C73: 100n; C_0603_1608Metric_Pad1.08x0.95mm_HandSolder
C6, C7: 15p; C_0603_1608Metric_Pad1.08x0.95mm_HandSolder
C8: 100u; CP_EIA-7343-31_Kemet-D_Pad2.25x2.55mm_HandSolder
C9, C10, C11, C12: 47p; C_0603_1608Metric_Pad1.08x0.95mm_HandSolder
C13: 2.2u; C_0805_2012Metric_Pad1.18x1.45mm_HandSolder
C14, C18, C19, C52, C53, C54, C55: 10u; C_0805_2012Metric_Pad1.18x1.45mm_HandSolder
C15: 100n; C_0805_2012Metric_Pad1.18x1.45mm_HandSolder
C16: 1u; C_0805_2012Metric_Pad1.18x1.45mm_HandSolder
C47: 10p; C_0603_1608Metric_Pad1.08x0.95mm_HandSolder
C58, C59, C60, C61, C62, C63, C64, C65, C66, C67, C68: 1u; C_0603_1608Metric_Pad1.08x0.95mm_HandSolder
CON1: CF-CARD-cfcard; TE_1734451-1-LONG
D1: LED_Red; LED_D3.0mm_Horizontal_O1.27mm_Z6.0mm
D2: LED_Green; LED_D3.0mm_Horizontal_O1.27mm_Z6.0mm
D3, D4, D9: MBR0520; D_SOD-123
D5: BAT54C; SOT-23
D6: LED_Blue; LED_D3.0mm_Horizontal_O1.27mm_Z6.0mm
D7: BZV55C5V6; D_MiniMELF
D8: BT168GW; SOT-223-3_TabPin2
F1: 2A; Fuse_1812_4532Metric_Pad1.30x3.40mm_HandSolder
H1, H2, H3, H4: Screw M3 dk=5mm L=4mm; MountingHole_3.2mm_M3_dk5.2mm_Mask
J1, J4: Mini-DIN-6; minidin-6
J2: PJ-322
J3: USB_B_Micro; USB_Micro-B_Molex-105017-0001
J5: DB15_Female_HighDensity_MountingHoles; DSUB-15-HD_Female_Horizontal_P2.29x1.98mm_EdgePinOffset3.03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
J6: Conn_01x04; PinHeader_1x04_P2.54mm_Vertical
J7: PC104_16; PinSocket_2x20_P2.54mm_Vertical
J8: PC104; PinSocket_2x32_P2.54mm_Vertical
J9: COM1; PinHeader_2x05_P2.54mm_Vertical
J10: COM2; PinHeader_2x05_P2.54mm_Vertical
J11: ESP; PinHeader_2x05_P2.54mm_Vertical
J12: Conn_02x07_Odd_Even; PinSocket_2x08_P2.54mm_Vertical
L1: 10u; L_Taiyo-Yuden_NR-60xx_HandSoldering
LOGO1: graphic; black-mage-12.5x8.6
LS1: Speaker; Buzzer_12x9.5RM7.6
Q1: BC817; SOT-23
Q2: BC856; SOT-23
R1, R2, R6, R7, R8, R20: 4.7k; R_0603_1608Metric_Pad0.98x0.95mm_HandSolder
R3: 33; R_0805_2012Metric_Pad1.20x1.40mm_HandSolder
R4: 10M; R_0603_1608Metric_Pad0.98x0.95mm_HandSolder
R5: 0; R_0603_1608Metric_Pad0.98x0.95mm_HandSolder
R10: 10k; R_0603_1608Metric_Pad0.98x0.95mm_HandSolder
R11, R21: 1k; R_0603_1608Metric_Pad0.98x0.95mm_HandSolder
R12, R13, R18: 470; R_0603_1608Metric_Pad0.98x0.95mm_HandSolder
R14: 113k; R_0603_1608Metric_Pad0.98x0.95mm_HandSolder
R15: 13.3k; R_0603_1608Metric_Pad0.98x0.95mm_HandSolder
R16, R17, R19: 22; R_0603_1608Metric_Pad0.98x0.95mm_HandSolder
R22: 51k; R_0603_1608Metric_Pad0.98x0.95mm_HandSolder
RN1, RN2, RN3, RN6: 4.7k; R_Array_Convex_4x0603
RN4, RN5: 330; R_Array_Convex_4x0603
RN8: 1k; R_Array_Convex_4x0603
SW1: SW_Push; SW_Tactile_SPST_Angled_PTS645Vx83-2LFS
SW2: Jumper / Pin header 1x2 Pitch=2.54mm; Molex_KK-254_AE-6410-02A_1x02_P2.54mm_Vertical
U1: CH340G; SOIC-16_3.9x9.9mm_P1.27mm
U2: ESP-12E
U3, U4: MSM5118160F-JS; SOJ-42
U5: M6117D; PQFP-208_28x28mm_P0.5mm
U6, U8: GD75232PW; TSSOP-20_4.4x6.5mm_P0.65mm
U7: 27C512; PLCC-32_11.4x14.0mm_P1.27mm-longpads
U9: AMS1117-3.3; SOT-223-3_TabPin2
U10: LT1930; SOT-23-5_HandSoldering
U11: TXB0104PW; TSSOP-14_4.4x5mm_P0.65mm
U12: MAX823LEUK; SOT-23-5
U13: ST16C554; LQFP-64_10x10mm_P0.5mm
U14: 74HCT32; TSSOP-14_4.4x5mm_P0.65mm
U15, U16: 74HCT138; TSSOP-16_4.4x5mm_P0.65mm
X1: 14.318 MHz; Oscillator_SMD_SeikoEpson_SG8002CA-4Pin_7.0x5.0mm
X2: 1.8432 Mhz; Oscillator_SMD_SeikoEpson_SG8002CA-4Pin_7.0x5.0mm
X3: 80 MHz; Oscillator_SMD_SeikoEpson_SG8002CA-4Pin_7.0x5.0mm
Y1: 12 MHz; Crystal_SMD_SeikoEpson_TSX3225-4Pin_3.2x2.5mm_HandSoldering
Y2: 32768 Hz; Crystal_SMD_SeikoEpson_MC306-4Pin_8.0x3.2mm_HandSoldering

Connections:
+3V3: C19.2, C45.2, C46.2, D5.1, U2.3 (EN), U2.8 (VCC), U2.17 (GPIO2), U9.2 (VO), U11.1 (VCCA), U11.8 (OE)
+5V: C4.1, C8.1, C13.2, C18.2, C20.2, C21.2, C22.2, C23.2, C24.2, C25.2, C26.2, C27.2, C28.2, C29.2, C30.2, C31.2, C32.2, C33.2, C34.2, C35.2, C36.2, C37.2, C38.2, C39.2, C44.2, C48.2, C49.2, C51.2, C52.1, C53.1, C54.1, C55.1, C56.1, C57.1, C58.2, C59.2, C60.2, C61.2, C62.2, C63.2, C64.1, C65.1, C66.1, C67.1, C68.1, C69.1, C70.1, C71.1, C72.1, C73.1, CON1.13 (VCC2), CON1.36 (~WE), CON1.38 (VCC1), CON1.44 (~REG), D1.2 (A), D2.2 (A), D6.2 (A), D7.1 (K), D8.2 (A), F1.1, J1.4, J4.4, J6.4, J7.34, J8.5, J8.57, L1.1, LS1.1, R1.1, R2.1, R5.1, R6.1, R7.1, R8.1, R10.1, R22.1, RN1.5 (R4.2), RN1.6 (R3.2), RN1.7 (R2.2), RN1.8 (R1.2), RN2.5 (R4.2), RN2.6 (R3.2), RN2.7 (R2.2), RN2.8 (R1.2), RN3.5 (R4.2), RN3.6 (R3.2), RN3.7 (R2.2), RN3.8 (R1.2), RN4.5 (R4.2), RN4.6 (R3.2), RN4.7 (R2.2), RN4.8 (R1.2), RN5.5 (R4.2), RN5.6 (R3.2), RN5.7 (R2.2), RN5.8 (R1.2), RN8.5 (R4.2), RN8.6 (R3.2), RN8.7 (R2.2), RN8.8 (R1.2), U1.11 (~RI), U1.16 (VCC), U3.1 (VCC), U3.6 (VCC), U3.21 (VCC), U4.1 (VCC), U4.6 (VCC), U4.21 (VCC), U5.1 (VCC1), U5.15 (VCC2), U5.38 (VCC3), U5.46 (VCC4), U5.53 (VCC5), U5.59 (VCC6), U5.76 (VCC7), U5.85 (VCC8), U5.105 (VCC9), U5.125 (VCC11), U5.137 (VCC12), U5.150 (VCC13), U5.157 (VCC14), U5.182 (VCC15), U5.197 (VCC16), U6.20 (VCC), U7.32 (VCC), U8.20 (VCC), U9.3 (VI), U10.5 (Vin), U11.14 (VCCB), U12.5 (VCC), U13.4 (VCC), U13.19 (RIB#), U13.21 (VCC), U13.35 (VCC), U13.52 (VCC), U13.63 (RIA#), U14.14 (VCC), U15.6 (E3), U15.16 (VCC), U16.16 (VCC), X1.1 (EN), X1.4 (V+), X2.1 (EN), X2.4 (V+), X3.1 (EN), X3.4 (V+)
+12V: C14.2, C40.2, C41.2, C47.1, D3.1 (K), J8.17, R14.1, U6.1 (VDD), U8.1 (VDD)
+BATT: C17.1, D5.3, U5.110 (VBAT)
-12V: C16.1, C42.2, C43.2, D9.2 (A), J8.13, U6.10 (VSS), U8.10 (VSS)
/0x2E8: U13.7 (CSA#), U15.11 (O4)
/0x2F8: U13.42 (CSD#), U15.9 (O6)
/0x3E8: U13.11 (CSB#), U15.10 (O5)
/0x3F8: U13.38 (CSC#), U15.7 (O7)
/14MHz: R16.2, R17.2, X1.3 (OUT)
/AEN: J8.22, RN3.1 (R1.1), U5.199 (AEN), U16.5 (E2)
/BALE: J8.55, U5.173 (BALE)
/BD0: R8.2, U3.10 (DQ7), U4.10 (DQ7), U5.75 (BD0)
/BD1: U3.9 (DQ6), U4.9 (DQ6), U5.74 (BD1)
/BD2: U3.8 (DQ5), U4.8 (DQ5), U5.73 (BD2)
/BD3: U3.7 (DQ4), U4.7 (DQ4), U5.72 (BD3)
/BD4: U3.5 (DQ3), U4.5 (DQ3), U5.71 (BD4)
/BD5: U3.4 (DQ2), U4.4 (DQ2), U5.70 (BD5)
/BD6: U3.3 (DQ1), U4.3 (DQ1), U5.69 (BD6)
/BD7: U3.2 (DQ0), U4.2 (DQ0), U5.68 (BD7)
/BD8: U3.33 (DQ8), U4.33 (DQ8), U5.67 (BD8)
/BD9: U3.34 (DQ9), U4.34 (DQ9), U5.66 (BD9)
/BD10: U3.35 (DQ10), U4.35 (DQ10), U5.64 (BD10)
/BD11: U3.36 (DQ11), U4.36 (DQ11), U5.63 (BD11)
/BD12: U3.38 (DQ12), U4.38 (DQ12), U5.62 (BD12)
/BD13: U3.39 (DQ13), U4.39 (DQ13), U5.61 (BD13)
/BD14: U3.40 (DQ14), U4.40 (DQ14), U5.60 (BD14)
/BD15: U3.41 (DQ15), U4.41 (DQ15), U5.58 (BD15)
/CAS0J0: U3.31 (~LCAS), U5.93 (CAS0LJ)
/CAS0J1: U3.30 (~UCAS), U5.92 (CAS0HJ)
/CAS1J0: U4.31 (~LCAS), U5.91 (CAS1LJ)
/CAS1J1: U4.30 (~UCAS), U5.90 (CAS1HJ)
/CD_COM1: U6.17 (RY3), U13.31 (CDC#)
/CD_COM2: U8.17 (RY3), U13.49 (CDD#)
/CLK2: R19.2, X3.3 (OUT)
/CTS1: J9.8, U6.9 (RA5)
/CTS2: J10.8, U8.2 (RA1)
/CTS_COM1: U6.12 (RY5), U13.33 (CTSC#)
/CTS_COM2: U8.19 (RY1), U13.47 (CTSD#)
/CTS_ESP: J11.10, U13.2 (CTSA#)
/CTS_USB: U1.14 (~RTS), U13.16 (CTSB#)
/DACK0: J7.18, RN6.7 (R2.2), U5.16 (DACK0J)
/DACK1: J8.33, RN6.6 (R3.2), U5.18 (DACK1J)
/DACK2: J8.51, U5.20 (DACK2J)
/DACK3: J8.29, U5.22 (DACK3J)
/DACK5: J7.22, RN6.5 (R4.2), U5.24 (DACK5J)
/DACK6: J7.26, U5.26 (DACK6J)
/DACK7: J7.30, U5.28 (DACK7J)
/DCD1: J9.1, U6.4 (RA3)
/DCD2: J10.1, U8.4 (RA3)
/DRQ0: J7.20, U5.17 (DRQ0)
/DRQ1: J8.35, U5.19 (DRQ1)
/DRQ2: J8.11, U5.21 (DRQ2)
/DRQ3: J8.31, U5.23 (DRQ3)
/DRQ5: J7.24, U5.25 (DRQ5)
/DRQ6: J7.28, U5.27 (DRQ6)
/DRQ7: J7.32, U5.29 (DRQ7)
/DSR1: J9.6, U6.7 (RA4)
/DSR2: J10.6, U8.3 (RA2)
/DSR_COM1: U6.14 (RY4), U13.32 (DSRC#)
/DSR_COM2: U8.18 (RY2), U13.48 (DSRD#)
/DSR_USB: U1.13 (~DTR), U13.17 (DSRB#), U13.18 (CDB#)
/DTR1: J9.4, U6.5 (DY1)
/DTR2: J10.4, U8.8 (DY3)
/DTR_COM1: U6.16 (DA1), U13.34 (DTRC#)
/DTR_COM2: U8.13 (DA3), U13.46 (DTRD#)
/DTR_USB: U1.10 (~DSR), U1.12 (~DCD), U13.15 (DTRB#)
/ESP_CTS: J11.7, U2.7 (GPIO13)
/ESP_RST: U2.1 (~RST), U11.5 (A4)
/ESP_RTS: J11.9, U2.4 (GPIO16)
/ESP_RX: J11.5, U2.21 (GPIO3/RXD)
/ESP_TX: J11.3, Q2.1 (B), U2.22 (GPIO1/TXD)
/HDCS0: CON1.7 (~CS0), U5.50 (HDCS0J)
/HDCS1: CON1.32 (~CS1), U5.54 (HDCS1J)
/IOCHK: J8.2, RN5.4 (R4.1), U5.196 (IOCHKJ)
/IOCHRDY: CON1.42 (IORDY), J8.20, RN4.2 (R2.1), U5.164 (IOCHRDY)
/IOCS16: CON1.24 (~IOCS16), J7.6, RN5.2 (R2.1), U5.3 (IO16J)
/IOR: CON1.34 (~IORD), J8.27, RN8.4 (R4.1), U5.166 (IORJ), U13.40 (IOR#)
/IOW: CON1.35 (~IOWR), J8.25, RN8.3 (R3.1), U5.167 (IOWJ), U13.9 (IOW#)
/IRQ3: J8.49, U5.152 (IRQ3), U14.11
/IRQ4: J8.47, U5.151 (IRQ4), U14.8
/IRQ5: J8.45, U5.149 (IRQ5)
/IRQ6: J8.43, U5.148 (IRQ6)
/IRQ7: J8.41, U5.147 (IRQ7)
/IRQ9: J8.7, U5.146 (IRQ9)
/IRQ10: J7.8, U5.153 (IRQ10)
/IRQ11: J7.10, U5.154 (IRQ11)
/IRQ14: CON1.37 (INTRQ), J7.16, U5.158 (IRQ14)
/IRQ15: J7.14, U5.159 (IRQ15)
/KBCLK: C10.1, J4.5, R6.2, U5.122 (KBCLK)
/KBDAT: C9.1, J4.1, R7.2, U5.123 (KBDATA)
/KBSJ: R20.2, U5.119 (ROMKBCSJ), U7.23 (~CE)
/LA17: J7.17, U5.207 (LA17)
/LA18: J7.15, U5.206 (LA18)
/LA19: J7.13, U5.205 (LA19)
/LA20: J7.11, U5.204 (LA20)
/LA21: J7.9, U5.203 (LA21)
/LA22: J7.7, U5.202 (LA22)
/LA23: J7.5, U5.201 (LA23)
/MA0: U3.17 (MA0), U4.17 (MA0), U5.108 (MA0)
/MA1: U3.18 (MA1), U4.18 (MA1), U5.107 (MA1)
/MA2: U3.19 (MA2), U4.19 (MA2), U5.106 (MA2)
/MA3: U3.20 (MA3), U4.20 (MA3), U5.103 (MA3)
/MA4: U3.23 (MA4), U4.23 (MA4), U5.102 (MA4)
/MA5: U3.24 (MA5), U4.24 (MA5), U5.101 (MA5)
/MA6: U3.25 (MA6), U4.25 (MA6), U5.100 (MA6)
/MA7: U3.26 (MA7), U4.26 (MA7), U5.99 (MA7)
/MA8: U3.27 (MA8), U4.27 (MA8), U5.98 (MA8)
/MA9: U3.28 (MA9), U4.28 (MA9), U5.97 (MA9)
/MASTER: J7.36, RN5.1 (R1.1), U5.198 (MASTERJ)
/MEMCS16: J7.4, RN5.3 (R3.1), U5.4 (MEM16J)
/MEMR: J7.19, RN3.3 (R3.1), U5.171 (MRDJ), U7.25 (~OE/VPP)
/MEMW: J7.21, RN3.4 (R4.1), U5.172 (MWTJ)
/MSCLK: C12.1, J1.5, R1.2, U5.34 (MSCLK)
/MSDAT: C11.1, J1.1, R2.2, U5.155 (IRQ12/MSDATA)
/NOWS: J8.15, RN4.1 (R1.1), U5.165 (NOWSJ)
/PWG: U5.113 (PWG), U12.1 (~RST)
/RASJ0: U3.14 (~RAS), U5.84 (RAS0J)
/RASJ1: U4.14 (~RAS), U5.83 (RAS1J)
/REFRESH: J8.37, RN4.3 (R3.1), U5.163 (REFRESHJ)
/RESETL: CON1.41 (~RESET), U5.120 (RESETLJ), U11.10 (B4)
/RI1: J9.9, U6.3 (RA2)
/RI2: J10.9, U8.7 (RA4)
/RI_COM1: U6.18 (RY2), U13.30 (RIC#)
/RI_COM2: U8.14 (RY4), U13.50 (RID#)
/RSTDRV: J8.3, U5.162 (RSTDRV), U13.27 (RESET)
/RTS1: J9.7, U6.6 (DY2)
/RTS2: J10.7, U8.6 (DY2)
/RTS_COM1: U6.15 (DA2), U13.36 (RTSC#)
/RTS_COM2: U8.15 (DA2), U13.44 (RTSD#)
/RTS_ESP: U11.11 (B3), U13.5 (RTSA#)
/RTS_USB: U1.9 (~CTS), U13.13 (RTSB#)
/RX1: J9.2, U6.2 (RA1)
/RX2: J10.2, U8.9 (RA5)
/RX_COM1: U6.19 (RY1), U13.29 (RXC)
/RX_COM2: U8.12 (RY5), U13.51 (RXD)
/RX_ESP: U11.13 (B1), U13.62 (RXA)
/RX_USB: U1.2 (TXD), U13.20 (RXB)
/SA0: CON1.20 (A0), J8.62, U5.195 (SA0), U7.11 (A0), U13.24 (A0)
/SA1: CON1.19 (A1), J8.60, U5.194 (SA1), U7.10 (A1), U13.23 (A1)
/SA2: CON1.18 (A2), J8.58, U5.193 (SA2), U7.9 (A2), U13.22 (A2)
/SA3: J8.56, U5.192 (SA3), U7.8 (A3), U15.3 (A2)
/SA4: J8.54, U5.191 (SA4), U7.7 (A4), U15.2 (A1)
/SA5: J8.52, U5.190 (SA5), U7.6 (A5), U16.6 (E3)
/SA6: J8.50, U5.189 (SA6), U7.5 (A6), U16.1 (A0)
/SA7: J8.48, U5.187 (SA7), U7.4 (A7), U16.2 (A1)
/SA8: J8.46, U5.186 (SA8), U7.29 (A8), U15.1 (A0)
/SA9: J8.44, U5.185 (SA9), U7.28 (A9), U16.3 (A2)
/SA10: J8.42, U5.184 (SA10), U7.24 (A10)
/SA11: J8.40, U5.183 (SA11), U7.27 (A11)
/SA12: J8.38, U5.181 (SA12), U7.3 (A12)
/SA13: J8.36, U5.180 (SA13), U7.30 (A13)
/SA14: J8.34, U5.179 (SA14), U7.31 (A14)
/SA15: J8.32, U5.178 (SA15), U7.2 (A15)
/SA16: J8.30, U5.177 (SA16)
/SA17: J8.28, U5.176 (SA17)
/SA18: J8.26, U5.175 (SA18)
/SA19: J8.24, U5.174 (SA19)
/SBHE: J7.3, U5.200 (BHEJ)
/SD0: CON1.21 (D0), J8.18, RN2.4 (R4.1), U5.145 (SD0), U13.53 (D0)
/SD1: CON1.22 (D1), J8.16, RN2.3 (R3.1), U5.144 (SD1), U13.54 (D1)
/SD2: CON1.23 (D2), J8.14, RN2.2 (R2.1), U5.143 (SD2), U13.55 (D2)
/SD3: CON1.2 (D3), J8.12, RN2.1 (R1.1), U5.142 (SD3), U13.56 (D3)
/SD4: CON1.3 (D4), J8.10, RN1.4 (R4.1), U5.141 (SD4), U13.57 (D4)
/SD5: CON1.4 (D5), J8.8, RN1.3 (R3.1), U5.140 (SD5), U13.58 (D5)
/SD6: CON1.5 (D6), J8.6, RN1.2 (R2.1), U5.139 (SD6), U13.59 (D6)
/SD7: CON1.6 (D7), J8.4, RN1.1 (R1.1), U5.138 (SD7), U13.60 (D7)
/SD8: CON1.47 (D8), J7.23, U5.5 (SD8)
/SD9: CON1.48 (D9), J7.25, U5.6 (SD9)
/SD10: CON1.49 (D10), J7.27, U5.7 (SD10)
/SD11: CON1.27 (D11), J7.29, U5.9 (SD11)
/SD12: CON1.28 (D12), J7.31, U5.10 (SD12)
/SD13: CON1.29 (D13), J7.33, U5.11 (SD13)
/SD14: CON1.30 (D14), J7.35, U5.12 (SD14)
/SD15: CON1.31 (D15), J7.37, U5.13 (SD15)
/SMEMR: J8.23, RN8.2 (R2.1), U5.168 (SMEMRJ)
/SMEMW: J8.21, RN8.1 (R1.1), U5.170 (SMEMWJ)
/SND_L: J2.T, J12.1
/SND_R: J2.R1, J12.2
/SPKR: J12.16, R11.1, U5.32 (SPKR)
/SYSCLK: J8.39, U5.160 (ATCLK)
/TC: J8.53, RN6.8 (R1.2), U5.14 (TC)
/TX1: J9.3, U6.8 (DY3)
/TX2: J10.3, U8.5 (DY1)
/TX_COM1: U6.13 (DA3), U13.39 (TXC)
/TX_COM2: U8.16 (DA1), U13.41 (TXD)
/TX_ESP: U11.12 (B2), U13.8 (TXA)
/TX_USB: U1.3 (RXD), U13.10 (TXB)
/UART_INTA: U13.6 (INTA), U14.9
/UART_INTB: U13.12 (INTB), U14.12
/UART_INTC: U13.37 (INTC), U14.10
/UART_INTD: U13.43 (INTD), U14.13
/USB_DN: J3.2 (D-), U1.6 (UD-)
/USB_DP: J3.3 (D+), U1.5 (UD+)
/VGA_B: J5.3, J12.13
/VGA_G: J5.2, J12.9
/VGA_HS: J5.13, J12.10
/VGA_MON: J5.12, J12.8
/VGA_R: J5.1, J12.5
/VGA_VS: J5.14, J12.14
/WEJ: U3.13 (~W), U4.13 (~W), U5.79 (WEJ)
/XD0: U5.136 (XD0), U7.13 (O0)
/XD1: U5.135 (XD1), U7.14 (O1)
/XD2: U5.134 (XD2), U7.15 (O2)
/XD3: U5.133 (XD3), U7.18 (O3)
/XD4: U5.131 (XD4), U7.19 (O4)
/XD5: U5.130 (XD5), U7.20 (O5)
/XD6: U5.129 (XD6), U7.21 (O6)
/XD7: U5.128 (XD7), U7.22 (O7)
/~CF_BUSY: CON1.45 (~DASP), R12.2
GND: BT1.2 (-), C1.1, C2.2, C3.2, C4.2, C5.2, C6.2, C7.2, C8.2, C9.2, C10.2, C11.2, C12.2, C13.1, C14.1, C16.2, C17.2, C18.1, C19.1, C20.1, C21.1, C22.1, C23.1, C24.1, C25.1, C26.1, C27.1, C28.1, C29.1, C30.1, C31.1, C32.1, C33.1, C34.1, C35.1, C36.1, C37.1, C38.1, C39.1, C40.1, C41.1, C42.1, C43.1, C44.1, C45.1, C46.1, C48.1, C49.1, C51.1, C52.2, C53.2, C54.2, C55.2, C56.2, C57.2, C58.1, C59.1, C60.1, C61.1, C62.1, C63.1, C64.2, C65.2, C66.2, C67.2, C68.2, C69.2, C70.2, C71.2, C72.2, C73.2, CON1.1 (GND1), CON1.8 (A10), CON1.9 (~ATASEL), CON1.10 (A9), CON1.11 (A8), CON1.12 (A7), CON1.14 (A6), CON1.15 (A5), CON1.16 (A4), CON1.17 (A3), CON1.39 (~CSEL), CON1.50 (GND2), CON1.S1 (Shield), CON1.S2 (Shield), D4.1 (K), D8.1 (K), J1.0, J1.3, J2.R2, J3.5 (GND), J3.6 (Shield), J4.0, J4.3, J5.0, J5.5, J5.6, J5.7, J5.8, J5.10, J7.1, J7.2, J7.38, J7.40, J8.1, J8.61, J8.63, J8.64, J9.5, J10.5, J11.2, J12.3, J12.4, J12.7, J12.11, J12.12, Q1.2 (E), Q2.3 (C), R13.2, R15.2, R20.1, R21.2, RN6.1 (R1.1), RN6.2 (R2.1), RN6.3 (R3.1), RN6.4 (R4.1), SW1.2, U1.1 (GND), U2.15 (GND), U2.16 (GPIO15), U3.22 (GND), U3.29 (~OE), U3.37 (GND), U3.42 (GND), U4.22 (GND), U4.29 (~OE), U4.37 (GND), U4.42 (GND), U5.8 (GND1), U5.31 (GND2), U5.40 (GND3), U5.52 (GND4), U5.65 (GND5), U5.81 (GND6), U5.94 (GND7), U5.104 (GND8), U5.118 (GND9), U5.121 (GND10), U5.132 (GND11), U5.156 (GND12), U5.161 (GND13), U5.169 (GND14), U5.188 (GND15), U5.208 (GND16), U6.11 (GND), U7.16 (GND), U8.11 (GND), U9.1 (GND), U10.2 (GND), U11.7 (GND), U12.2 (GND), U13.14 (GND), U13.28 (GND), U13.45 (GND), U13.61 (GND), U14.1, U14.2, U14.4, U14.5, U14.7 (GND), U15.5 (E2), U15.8 (GND), U16.4 (E1), U16.8 (GND), X1.2 (GND), X2.2 (GND), X3.2 (GND), Y1.2, Y1.4, Y2.2, Y2.3
unnamed: BT1.1 (+), D5.2
unnamed: C1.2, U1.4 (V3)
unnamed: C2.1, U1.7 (XI), Y1.1
unnamed: C3.1, U1.8 (XO), Y1.3
unnamed: C5.1, Q1.3 (C), R3.2
unnamed: C6.1, R4.1, U5.111 (XTAL1), Y2.1
unnamed: C7.1, R4.2, U5.112 (XTAL2), Y2.4
unnamed: C15.1, D3.2 (A), L1.2, U10.1 (SW)
unnamed: C15.2, D4.2 (A), D9.1 (K)
unnamed: C47.2, R14.2, R15.1, U10.3 (FB)
unnamed: D1.1 (K), R12.1
unnamed: D2.1 (K), R13.1
unnamed: D6.1 (K), R18.1
unnamed: D7.2 (A), D8.3 (G), R21.1
unnamed: F1.2, SW2.2 (B)
unnamed: J3.1 (VBUS), SW2.1 (A)
unnamed: J5.9, R5.2
unnamed: J6.1, R3.1
unnamed: J6.2, LS1.2
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

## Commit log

2021-11-24 pcb rev.A wip
    [charon386_main.kicad_pcb, charon386_main.kicad_sch, charon386_top.kicad_pcb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]
2021-12-13 wip pcb rev.A
    [charon386_main.kicad_pcb, charon386_main.kicad_sch, charon386_top.kicad_pcb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]
2022-06-17 wip pcb rev.A (almost done now)
    [charon386_covers.kicad_pcb, charon386_top.kicad_sch]
2022-09-12 wip pcb rev.A; rename charon -> kharon
    [charon386_covers.kicad_pcb, charon386_covers.kicad_sch, charon386_main.kicad_sch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]
2022-09-22 pcb rev.A final version
    [kharon386_covers.kicad_pcb, kharon386_main.kicad_sch, kharon386_top.kicad_sch]
2023-09-16 add pcb_main rev.A1
    [kharon386_main.kicad_sch]
2023-09-16 add pcb_top rev.A1
    [kharon386_top.kicad_sch]
2023-09-16 update pcb files for kicad 7.0 and grid 1.27
    [kharon386_main.kicad_sch, kharon386_top.kicad_sch]
2023-09-16 update errata for pcb_top rev.A
2023-09-16 wip pcb rev.A1
    [kharon386_main.kicad_sch, kharon386_top.kicad_pcb, kharon386_top.kicad_sch]
2023-09-16 update all pcb rev.A1 files - minor changes
    [kharon386_main.kicad_sch, kharon386_top.kicad_pcb, kharon386_top.kicad_sch]
2023-09-16 release all pcbs
